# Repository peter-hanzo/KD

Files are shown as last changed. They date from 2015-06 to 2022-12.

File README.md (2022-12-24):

## Круглый дом (КД) 
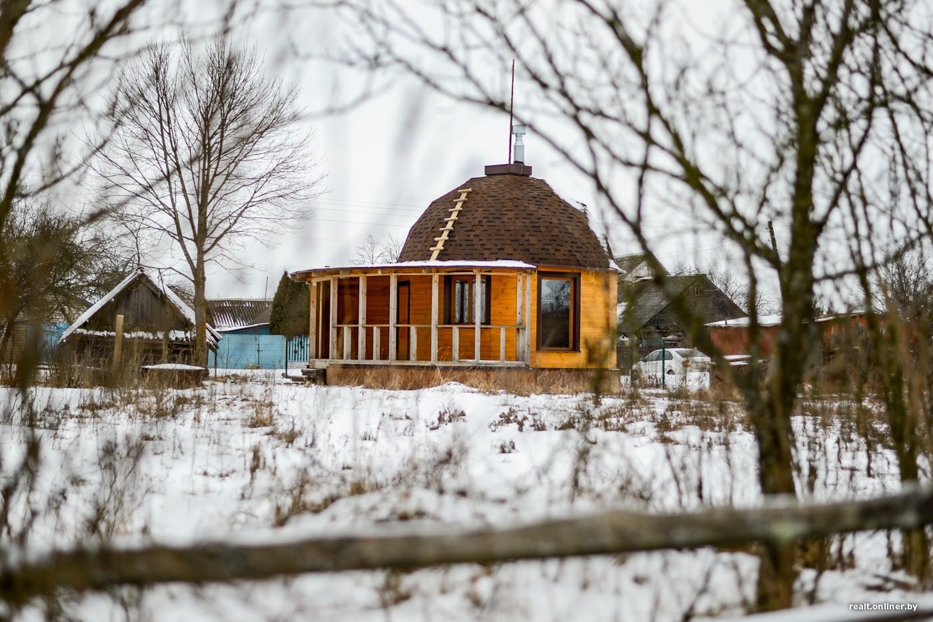
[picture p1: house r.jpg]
Текущий внешний вид


### Общие данные:
Одноквартирного жилого дом летнего типа _общей площадью 65м2_  
Выполнен в соответствии с функциональными желаниями Заказчика.  
Предназначен для строительства в Минской области.  

### Строительные решения разработаны для следующих условий:

Температура воздуха наиболее холодной пятидневки -30°С  
_Снеговая нагрузка:_ 180кг/м2  
_Скоростной напор ветра:_ 21 м/с на м2 
Расчетная температура наружного воздуха -35°С/+35°С  
Продолжительность периода со среднесуточной температурой менее 0°С =231сут  
Средняя максимальная температура воздуха наиболее теплого месяца +25°С  
Количество осадков за год 582мм  
Преобладающее направление ветра сентябрь-март «СЗ». март-сентябрь «ЮЗ»  
Зона влажности - нормальная  

### Планировочное решения:

За условную отметку 0.000 принят уровень чернового пола первого этажа.  
Планировка решена в 2-х уровнях:  
На первом этаже: прихожая, кладовая, коридор, гостиная, кухня, сан.узел, открытая терраса общей площадью 15 м2  
На втором этаже: спальня  
Первый и второй этажи соединены лестницей из деревянных конструкций  
Расположение дома на земельном участке обеспечивает естественную инсоляцию жилых помещений в соответствии требованиями энергоэффективности    
### Конструктивное решения:
Несущими конструкциями здания являются наружные стены.  
Пространственная жесткость здания обеспечивается совместной работой наружных и внутренних стен с элементами перекрытии.  
Ограждающие конструкции здания выполнены из дерева с утеплением из льна.  
Тип фундамента - свайно-буронабивной.  
На основании расчетных нагрузок от здания и типа грунта глубина заложения свай составляет 1,8м, диаметр свай 300мм.  
Наружные стены — доска 150*50 естественной влажности, льняной утеплитель 100мм + 50мм 
Стены обшиты имитацией бруса с вентилируемым фасадом.  
В качестве опоры второго этажа использован брус 200х200мм.  
Отделка помещения: Половая доска, фанера ФСФ, деревянный брус.  
* Перекрытия:_ деревянная балка.
* Лестница:_ деревянная  
* Крыша: Купольная из деревянных конструкций геодезического типа.  
* Кровля : битумная черепица  
* Окна: Деревянные с двойным стеклопакетом  
* Двери: деревянные  
* Полы: деревянные  

### Инженерное оборудование:
В жилом доме предусматривается следующее инженерное оборудование:  
* Отопление - от электрический кварцевых обогревателей  
* Холодное водоснабжение - от скважины глубиной 8м  
* Канализация — местная, бетонные кольца с переливом  
* Электроснабжение централизованное от местной электросети 220В  
* Газоснабжение  - отсутствует  

### Основные показатели проекта:
Этажность: 2 этажа  
Площадь застройки: 90 м2  
Общая площадь: 65 м2  
Жилая площадь: 35 м2  
Строительный объем: 170 м3  	
Класс ответственности здания: 4й — временные общественные здания и малоэтажные жилые дома с минимальным благоустройством  
Степень долговечности: 3я —  с пониженным сроком службы (не менее 20 лет)   
Степень огнестойкости: 5я - сгораемые  

Читайте все посты по данному проекту [в блоге](https://rdnk.by)

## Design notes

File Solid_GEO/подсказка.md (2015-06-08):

frame.SLDASM - сама модель.
frame.SLDDRW - некое подобие документации (в корне папки аналогичная pdf'ка).

Если нет solidworks'a можно посмотреть в бесплатном просмотрщике edrawing viewer 2015
http://www.edrawingsviewer.com/ed/download.htm.

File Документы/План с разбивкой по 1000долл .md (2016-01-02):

КРОВЛЯ ДОМА 
- [ ] Смонтировать дверь в доме 100 (80-120)
- [ ] Сделать обрамления окон в доме 60 (40-80)		
- [ ] Закрепить верхний слой кровли дома 450 (300-600)
- [ ] Смонтировать водостоки дома 375 (250-500)
- [ ] *** 985$

ПОЛНАЯ ЗАЩИТА ДОМА ОТ ВНЕШНЕЙ СРЕДЫ
- [ ] Смонтировать окна	в доме 1100 (750-1450)
- [ ] *** 1100$

КРЫЛЬЦО + ЭЛЕКТОПРОВОДКА ПО ВСЕМУ ДОМУ
- [ ] Смонтировать каркас крыльца 40 (30-50)  
- [ ] Подшить пол крыльца 20 (10-30)
- [ ] Уложить чистовой пол крыльца 55 (30-80) 
- [ ] Смонтировать крышу крыльца 75 (50-100)
- [ ] Смонтировать лестницу крыльца 35 (20-50)		
- [ ] Нанести пропитку на внешнюю обшивку стен дома 75 (50-100)
- [ ] Проложить кабель от счетчика к дому 150 (100-200)				
- [ ] Установить электроящик и автоматы 165 (80-250)		
- [ ] Проложить кабель в доме +розетки 200 (100-300)
- [ ] *** 930$

УТЕПЛЕННЫЙ ПОЛ ПЕРВОГО ЭТАЖА
- [ ] Смонтировать утеплитель 6м3 пола первого этажа 225 (150-300)
- [ ] Смонтировать мембрану пола первого этажа 100 (80-120)		
- [ ] Смонтировать подшивку пола первого этажа 225 (150-300)
- [ ] Зашить подпольное простанство дома 265 (180-350)				
- [ ] *** 815$

УТЕПЛЕННЫЙ И ОБШИТЫЙ КУПОЛ ДОМА
- [ ] Смонтировать утеплитель в куполе 700 (400-1000) 			
- [ ] Смонтировать внутренюю мембрану в куполе 140 (80-200)
- [ ] Смонтировать внутренюю обшивку в куполе 550 (300-800)
- [ ] *** 1390$

УТЕПЛЕННЫЕ И ОБШИТЫЕ СТЕНЫ ДОМА
- [ ] Смонтировать утеплитель в стены дома 550 (300-800)			
- [ ] Смонтировать внутренюю мембрану в стены дома 100 (50-150)
- [ ] Смонтировать внутренюю обшивку стен дома 450 (300-600)
- [ ] *** 1100$

ОТОПЛЕНИЕ В ДОМЕ
- [ ] Установить систему отопления в доме 900 (200-1600)			
- [ ] *** 900$

ВОДОПРОВОД И КАНАЛИЗАЦИЯ		
- [ ] Установить канализацию 800 (400-1200)
- [ ] Прокложить трубы канализации и водопровода 200 (100-300)
- [ ] Установить насос для водопровода 325 (200-450)
- [ ] *** 1325$

ВТОРОЙ ЭТАЖ
- [ ] Смонтировать каркас второго этажа 125 (50-200)
- [ ] Уложить утеплитель второго этажа 200 (100-300) 
- [ ] Подшить потолок второго этажа 100 (50-150) 
- [ ] Уложить чистовой пол  второго этажа 200 (100-300)
- [ ] Смонтировать ограждение второго этажа 200 (50-350)
- [ ] *** 825$

ЛЕСТНИЦА + ПОЛ ПЕРВОГО ЭТАЖА
- [ ] Изготовить лестницу второго этажа 275 (50-500)	
- [ ] Смонтировать лестницу второго этажа 100 (50-150)
- [ ] Смонтировать чистовой пол первого этажа 400 (300-500)			
- [ ] *** 775$

НЕОТАПЛИВАЕМЫЙ САНУЗЕЛ С КРЫШЕЙ
- [ ] Смонтировать фундамент санузла 125 (50-200)
- [ ] Смонтировать обвязку санузла 200 (100-300)
- [ ] Собрать каркас стен санузла 150 (100-200)
- [ ] Собрать купол санузла 225 (150-300)
- [ ] Накрыть крышу санузла 300 (200-400)
- [ ] Установить окно санузла 250 (200-300)
- [ ] Установить дверь санузла 115 (80-150)
- [ ] *** 1365$	

ПОЛНОЦЕННЫЙ ОТАПЛИВАЕМЫЙ САНУЗЕЛ						
- [ ] Подшить пол санузла 100 (50-150)		
- [ ] Утеплить пол санузла 100 (50-150)
- [ ] Смонтировать чистовой пол санузла 225 (150-300)
- [ ] Смонтировать черновой пол санузла 150 (100-200)
- [ ] Смонтировать внешнюю мембрану	санузла 60 (40-80)	
- [ ] Утеплить купол санузла 225 (150-300)
- [ ] Утеплить стены санузла 175 (100-250)							
- [ ] Зашить подпольное простанство санузла 100 (50-150)
- [ ] Установить систему отопления в санузле 150 (100-200)	
- [ ] Установить бойлер 300 (150-450)  
- [ ] *** 1585$

ВЕРАНДА С КРЫШЕЙ	
- [ ] Смонтировать фундамент веранды 125 (50-200)
- [ ] Смонтировать обвязку веранды 200 (100-300)
- [ ] Уложить пол веранды 225 (150-300) 
- [ ] Пропитать пол веранды 75 (50-100)
- [ ] Смонтировать крышу веранды 450 (300-600)
- [ ] Смонтировать лестницу веранды 100 (50-150)
- [ ] *** 1175$

ЗОБОР И РАЗМЕТКА УЧАСТКА		
- [ ] Установить забор 50м 600 (300-900)
- [ ] Установить ворота и калитку 175 (50-300)
- [ ] Уложить дорожки 200 (100-300)
- [ ] *** 975$

ПОРЯДОК НА УЧАСТКЕ
- [ ] Переместить гараж 100 (50-150)
- [ ] Распилить, поколоть, сложить дрова 175 (100-250)		
- [ ] Выровнять уровень грунта на участке 300 (200-400)
- [ ] Сделать отмостку вокруг дома 200 (100-300)
- [ ] Завести плодородный грунт 225 (150-300)
- [ ] *** 1000$

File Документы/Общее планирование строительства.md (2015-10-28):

- [x] Выбрать участок  
- [x] Обеспечить коммуникаций  
	- [x] Дороги (получить гарантированный подвоз материалов)  
	- [x] Электричество  (постоянно иметь 220V на участке)
	- [x] Вода  (постояно иметь воду в любом количестве)
- [x] Подготовить участок  
	- [x] Получить разрешения на снос старых построек  
	- [x] Разобрать старые постройки  
	- [x] Расчистить площадку под застройку  
	- [x] Обозначить границы участка согласно документам  
	- [x] Выбрать расположение будущего дома и его размеры  
- [x] Разработать архитектуру  
	- [x] Выбрать архитектора  
	- [x] Составить планировку внутренних помещений  
	- [x] Определить расположение дверей и окон  
- [x] Разработать конструкцию всего дома  
	- [x] Фундамент  
		- [x] Выбрать тип фундамента 
		- [x] Определить точное расположение на участке 
		- [x] Рассчитать глубину, ширину, высоту  
	- [x] Стены  
		- [x] Создать конструкцию  
		- [x] Выбрать материалы конструкции  
		- [ ] Выбрать утеплитель 
		- [ ] Выбрать тип отделки  
	- [x] Крыша  
		- [x] Создать форму и конструкцию  
		- [x] Выбрать материалы  
		- [ ] Выбрать утеплитель для пола
		- [ ] Выбрать утеплитель для купола
		- [ ] Выбрать утеплитель для стен
	- [ ] Окна и двери  
		- [x] Выбрать конструкцию  
		- [x] Определить точные размеры
		- [x] Определить расположение
		- [ ] Выбрать материал изготовления  
	- [ ] Электрика
		- [ ] Определить путь прокладки кабеля от щитка	
		- [ ] Определить точное расположение розеток и выключателей  
		- [x] Рассчитать максимальные нагрузки  
		- [ ] Определить место установки счетчика  
		- [ ] Рассчитать необходимые материалы  
	- [ ] Канализация  
		- [ ] Определить точное расположение  
		- [ ] Выбрать тип конструкции  
		- [ ] Расчитать необходимый объем  
		- [ ] Выбрать материалы  
- [x] Получить разрешение на стройку  
	- [x] Выяснить необходимый список документов и орган согласования  
	- [x] Подать пакет документов  
- [x] Построить здание  
	- [x] Фундамент  
		- [x] Рассчитать и закупить материалы  
		- [x] Связать арматуру
  		- [x] Заготовить трубки из руберойда
		- [x] Разметить границы и уровни  
		- [x] Залить и обрезать в уровень
	- [x] Обвязка и пол  
		- [x] Рассчитать  и закупить брус, лаги, крепления  
		- [x] Нарезать брус в размер под углом  
		- [x] Нанести пропитку  
		- [x] Смонтировать обвязку
		- [ ] Смонтировать мембрану пола первого этажа (80-120)		
		- [ ] Смонтировать подшивку пола первого этажа(150-300)
		- [ ] Смонтировать утеплитель 6м3 пола первого этажа(150-300)		
		- [ ] Смонтировать чистовой пол первого этажа(300-500)
	- [ ] Стены  
		- [x] Расчитать и закупить доску  
		- [x] Нарезать заготовки
		- [x] Заготовить сегменты стен
		- [x] Смонтировать сегменты стен			
		- [x] Смонтировать внешнюю мембрану			
		- [x] Ненести пропитку на внешнюю обшивку стен дома (50-100)
		- [x] Смонтировать внешнюю обшивку дома (0)
		- [ ] Зашить подпольное простанство дома(180-350)		
		- [ ] Смонтировать утеплитель в стены дома (300-800)			
		- [ ] Смонтировать внутренюю мембрану в стены дома(50-150)			
  		- [ ] Смонтировать внутренюю обшивку стен дома (300-600)
	- [ ] Купол  
		- [x] Расчитать и закупить доску  
		- [x] Нарезать заготовки
		- [x] Заготовить сегменты стен
		- [x] Смонтировать сегменты стен			
		- [ ] Смонтировать утеплитель в купол(400-1000) 			
		- [ ] Смонтировать внутренюю мембрану в купол (80-200)			
  		- [ ] Смонтировать внутренюю обшивку в купол (300-800)		
	- [ ] Крыша  
		- [x] Закупить крепления, доску, фанеру, бруски, кровлю, водостоки 
		- [x] Нарезать доску в размер под углом  
		- [x] Смонтировать каркас купола  
		- [x] Зашить каркас купола пленкой  
		- [x] Смонтировать бруски
  		- [x] Заготовить треугольники из фанеры
		- [x] Смонтировать треугольники  
		- [x] Приклеить нижний слой кровли  
		- [ ] Закрепить верхний слой кровли дома (300-600)  
		- [ ] Смонтировать водостоки дома(250-500)
	- [ ] Окна и двери  
		- [ ] Смонтировать проемы для окон в доме (0)
		- [ ] Смонтировать проемы для двери в доме (0)
		- [ ] Смонтировать дверь в доме (80-120)
		- [ ] Смонтировать окна	в доме (750-1450)
		- [ ] Сделать обрамления окон в доме (40-80)		
	- [ ] Второй этаж  
		- [ ] Смонтировать каркас второго этажа (50-200)
		- [ ] Уложить утеплитель второго этажа (100-300) 
		- [ ] Подшить потолок второго этажа (50-150) 
		- [ ] Уложить чистовой пол  второго этажа (100-300)
		- [ ] Смонтировать ограждение второго этажа (50-350)
		- [ ] Изготовить лестницу второго этажа (50-500)	
		- [ ] Смонтировать лестницу второго этажа(50-150)
	- [ ] Крыльцо  
		- [x] Смонтировать обвязку
		- [ ] Смонтировать каркас крыльца (30-50)  
		- [ ] Подшить пол крыльца (10-30) 
		- [ ] Уложить чистовой пол крыльца (30-80) 
		- [ ] Смонтировать крышу крыльца (50-100)
		- [ ] Смонтировать лестницу крыльца (20-50)
	- [ ] Веранда  
		- [ ] Смонтировать фундамент веранды (50-200)
		- [ ] Смонтировать обвязку веранды (100-300) 
		- [ ] Уложить пол веранды (150-300) 
		- [ ] Пропитать пол веранды (50-100) 		
		- [ ] Смонтировать крышу веранды (300-600)
		- [ ] Смонтировать лестницу веранды (50-150)
	- [ ] Обуствойство быта  
		- [ ] Смонтировать раковину в доме (50-100)
		- [ ] Смонтировать шкафы в доме(100-300) 
	- [ ] Отдельный санузел  
		- [ ] Смонтировать фундамент санузла (50-200)
		- [ ] Смонтировать обвязку санузла (100-300)
		- [ ] Собрать каркас стен санузла (100-200)
		- [ ] Собрать купол санузла (150-300)
		- [ ] Накрыть крышу санузла (200-400)
		- [ ] Подшить пол санузла (50-150)		
		- [ ] Утеплить пол санузла (50-150)
		- [ ] Смонтировать чистовой пол санузла (150-300)
		- [ ] Смонтировать внешнюю мембрану	санузла (40-80)	
		- [ ] Утеплить стены санузла санузла (100-250)
		- [ ] Утеплить купол санузла санузла (150-300)
		- [ ] Установить окно санузла (200-300)
		- [ ] Установить дверь санузла (80-150)
		- [ ] Зашить подпольное простанство санузла (50-150)
- [ ] Канализация и водопровод
	- [ ] Прокладка труб (100-300)
	- [ ] Установка септика (300-3200)
	- [ ] Установка насоса (200-450)
	- [ ] Установка бойлера (150-450)  	
- [ ] Электричество
	- [ ] Прокладка кабеля от счетчик к дому (100-200)
   	- [ ] Установка электро ящика и автоматов (80-250)		
   	- [ ] Прокладка кабеля в доме +розетки (100-300)
- [ ] Благоустройство територии
	- [ ] Выровнять уровень грунта на участке (200-400)
   	- [ ] Завести плодородный грунт (150-300)
   	- [ ] Распилить, поколоть, сложить дрова (100-250)		
   	- [ ] Установить забор 50м (300-900)
   	- [ ] Переместить гараж (50-150)		
   	- [ ] Установить ворота и калитку (50-300)
   	- [ ] Сделать отмостку вокруг дома (100-300)
   	- [ ] Уложить дорожки (100-300)
- [ ] Установить систему отопления в доме (200-1000)
- [ ] Установить систему отопления в санузле (100-200)

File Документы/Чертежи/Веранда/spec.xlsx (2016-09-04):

Поз | Сечение, мм | Длина, мм | Кол-во
1 | 150x50 | 3015 | 26
2 |  | 2150 | 27
3 |  | 1245 | 4
4 |  | 2364 | 4
5 |  | 2283 | 4
6 |  | 2160 | 2
7 |  | 567 | 1
8 |  | 528 | 1
9 |  | 533 | 2
10 |  | 600 | 2
11 |  | 1099 | 1
12 |  | 1350 | 1
13 |  | 1099 | 2
14 |  | 504 | 1
15 |  | 480 | 2
16 |  | 516 | 1
17 |  | 646 | 2
18 |  | 1312 | 2
19 |  | 1306 | 2
20 |  | 1188 | 1
21 |  | 2058 | 1
22 |  | 900 | 4
23 |  | 1046 | 1
24 |  | 1317 | 2
25 |  | 1317 | 2
26 |  | 1035 | 1
27 |  | 1081 | 1
28 |  | 1345 | 2
29 |  | 1345 | 2
30 |  | 1081 | 1
31 |  | 1144 | 1
32 |  | 1316 | 1
33 |  | 1316 | 1
34 |  | 2198 | 2
35 |  | 2203 | 2
36 |  | 2306 | 2
37 |  | 1256 | 4
40 |  | 2600 | 44
41 |  | 2310 | 2
42 |  | 2305 | 2
43 |  | 968 | 9
44 |  | 2467 | 1
45 |  | 2462 | 1
46 |  | 2376 | 1
47 |  | 2371 | 1
48 |  | 808 | 3
49 |  | 1050 | 2
50 |  | 1387 | 2
51 |  | 1037 | 2
52 |  | 687 | 2
53 |  | 1268 | 2
54 |  | 975 | 2
55 |  | 683 | 2
56 |  | 1296 | 2
57 |  | 990 | 2
58 |  | 685 | 2
59 |  | 1245 | 2
60 |  | 962 | 2
61 |  | 682 | 2
62 |  | 1292 | 2
63 |  | 988 | 2
64 |  | 685 | 2
65 |  | 1211 | 2
66 |  | 918 | 2
67 |  | 625 | 2
68 |  | 2336 | 2
69 |  | 2312 | 2
70 |  | 2293 | 2
71 |  | 2313 | 2
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

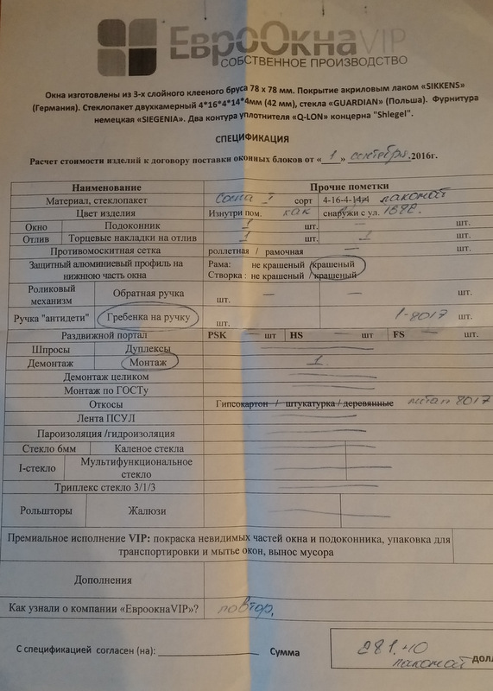
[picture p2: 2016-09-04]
Документы/Фактические расходы/2016-09/2016-09-01 - 573.00 - 291$ - Санузел - изготовление и монтаж окна.jpg

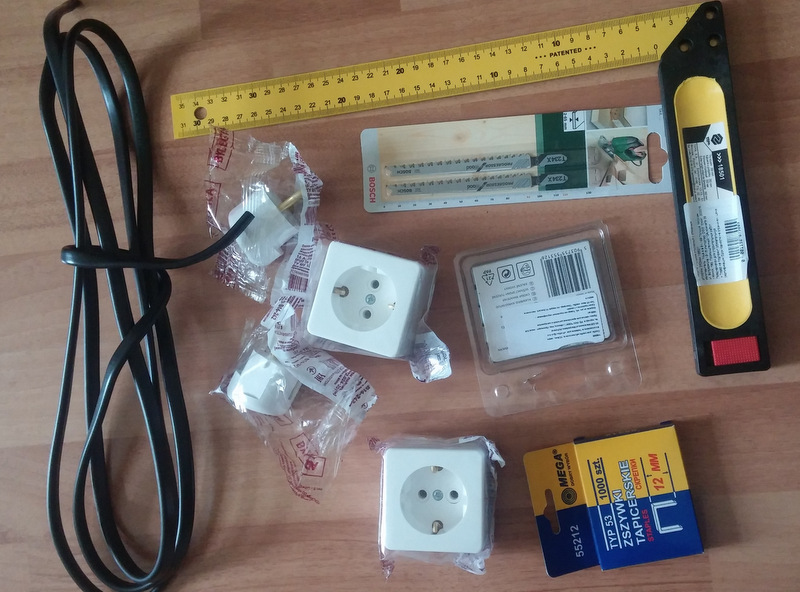
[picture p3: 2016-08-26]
Документы/Фактические расходы/2016-08/2016-08-15 - 55.00 - 28$ - Первый этаж - инструмент и комплектующие.jpg

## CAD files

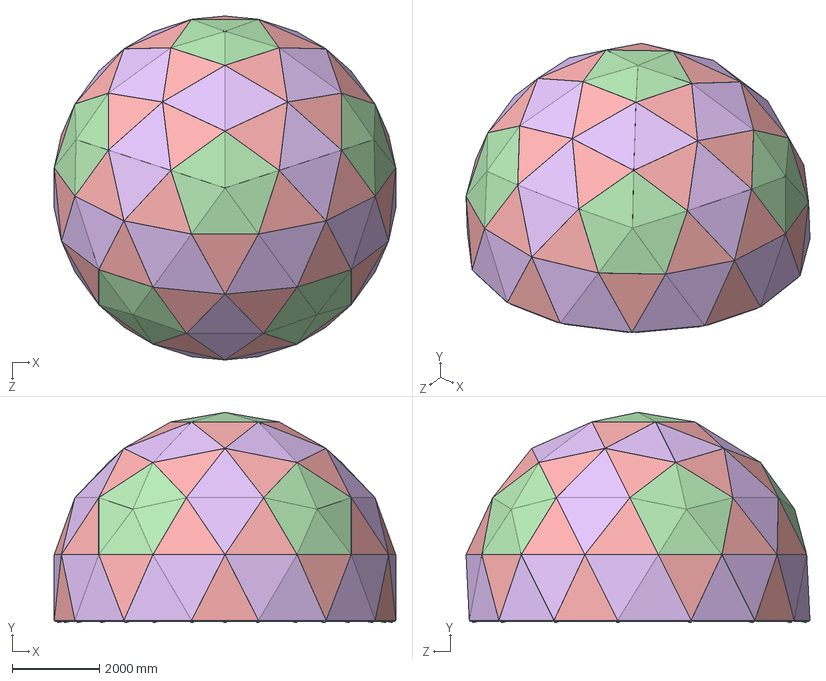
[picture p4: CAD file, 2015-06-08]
Solid_GEO/frame/frame.SLDASM
7818.9 x 4812.3 x 7874.0 mm
board_1 x 45
plate_1 x 180
pin x 760
nut x 1520
board_2 x 35
plate_2 x 140
board_3 x 80
plate_3 x 320
board_4 x 30
plate_4 x 120
pipe x 90
triangle_1 x 30
triangle_2 x 35
triangle_3 x 40

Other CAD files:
Документы/Чертежи/Архитектура (эскизный)/генплан v2.dwg
Документы/Чертежи/Конструктив/треугольники.dwg
Документы/Чертежи/Крыша/Металл-профиль.dwg
Что бывает/Чертежи/купол.dwg
Документы/Чертежи/Конструктив/Схема сборки и обшивки каркаса.dwg
Что бывает/Чертежи/Polusfera_v_liniakh_3V_6m.dwg
Документы/Чертежи/Конструктив/Спецификация балок обвязки.dwg
Документы/Чертежи/Конструктив/терасса.dwg
Документы/Чертежи/Конструктив/пластины и уголок.dwg
Solid_GEO/frame/board_1.SLDPRT
Solid_GEO/frame/board_2.SLDPRT
Solid_GEO/frame/frame.SLDDRW
Solid_GEO/frame/frame.SLDPRT
Solid_GEO/frame/nut.SLDPRT
Solid_GEO/frame/pin_nut.SLDASM
Solid_GEO/frame/pipe.SLDPRT
Solid_GEO/frame/plate_1.SLDPRT
Solid_GEO/frame/plate_2.SLDPRT
Solid_GEO/frame/plate_4.SLDPRT
Solid_GEO/frame/triangle_1.SLDPRT
Solid_GEO/frame/triangle_2.SLDPRT
Solid_GEO/frame/triangle_3.SLDPRT
Документы/Чертежи/Архитектура (эскизный)/генплан.dwg
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

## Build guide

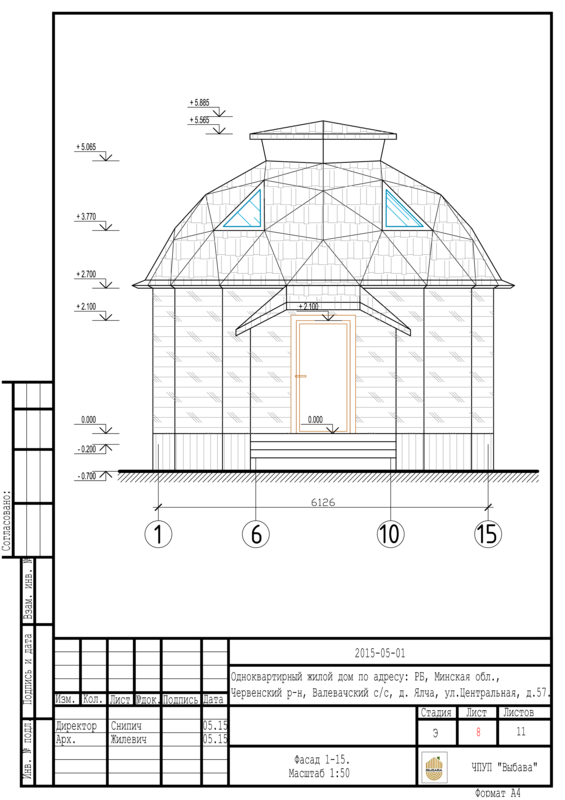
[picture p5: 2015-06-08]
Документы/Чертежи/Архитектура (эскизный)/printable/лист 8 фасад.png

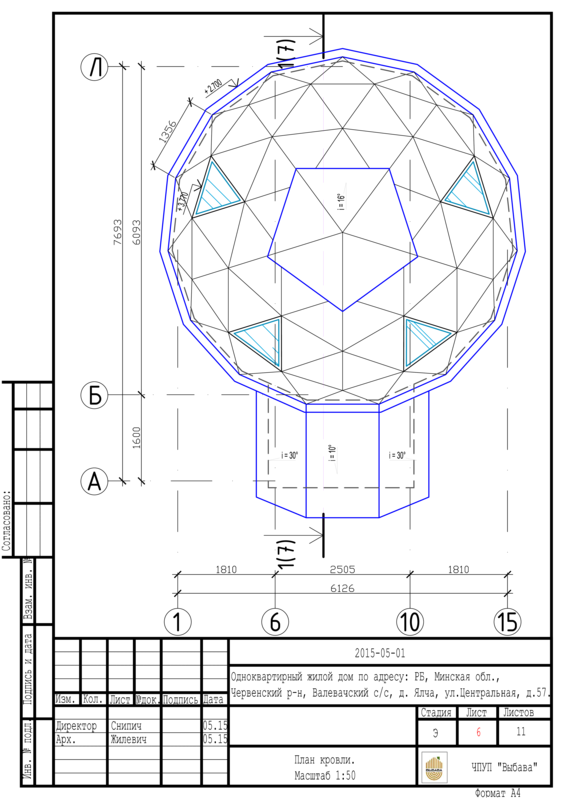
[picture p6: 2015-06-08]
Документы/Чертежи/Архитектура (эскизный)/printable/лист 6 план кровли А4.png

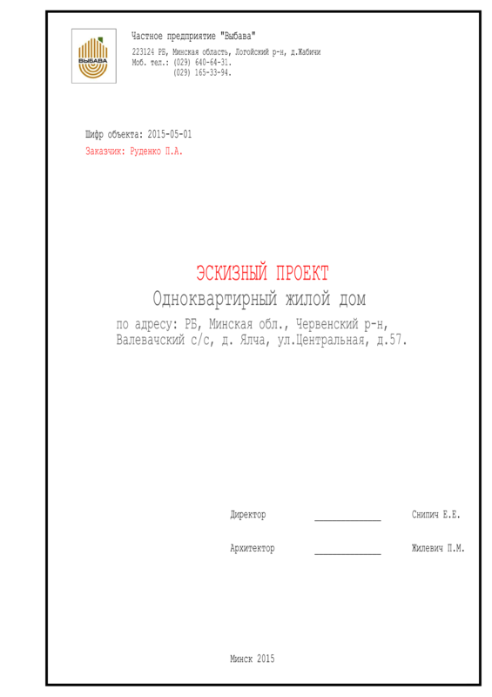
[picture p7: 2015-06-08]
Документы/Чертежи/Архитектура (эскизный)/printable/титульник А4.png

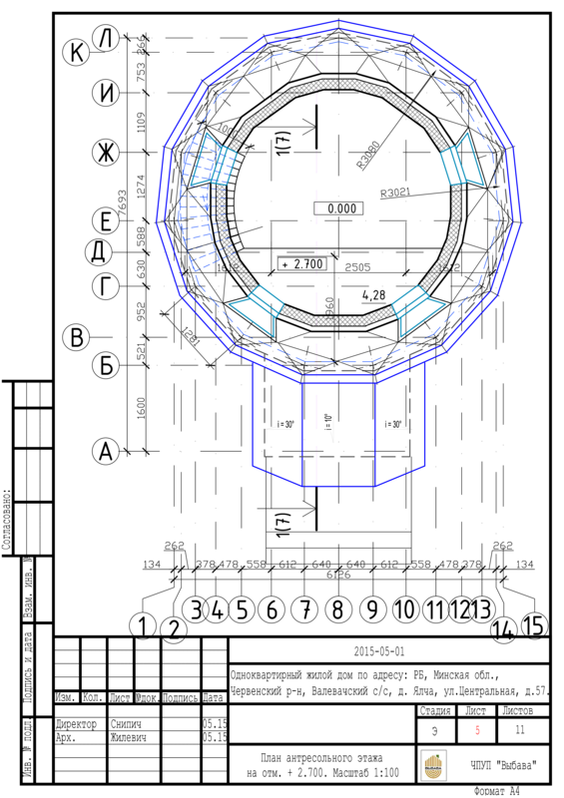
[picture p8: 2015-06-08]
Документы/Чертежи/Архитектура (эскизный)/printable/лист 5 план антресолей А4.png

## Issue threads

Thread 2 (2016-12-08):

переписать описание в корне проекта

Komzpa, 2016-12-08:
Слова "самостоятельно" и "$1000 ежемесячно" - это не про этот проект :)

RudenkoPeter, 2016-12-08:
согласен, уже не про этот)

RudenkoPeter, 2016-12-19:
Так норм? "Каждый год комфортно проживать в период весна-осень"

Komzpa, 2016-12-19:
у этого дома уже зафиксирована площадь, этажность и другие параметры. можно писать их, а не требования двухгодичной давности :)

RudenkoPeter, 2016-12-19:
Может убрать "требования" и написать паспорт объекта?

Komzpa, 2016-12-19:
похоже на то.

Closed 2017-05-21.

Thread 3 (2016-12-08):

Схема коммуникаций

Komzpa, 2016-12-08:
Нужна схема:
 - всей электрики в доме (установленной и планируемой);
 - всей канализации в доме (установленной и планируемой).

RudenkoPeter, 2016-12-08:
Достаточно ли сделать в 3д  или нужны чертежи?

RudenkoPeter, 2016-12-08:
Вот в таком виде + отдельная модель в Sketchup ?
https://sketchfab.com/models/3d5a06f5ac784347bc1c8a6937288433

Komzpa, 2016-12-08:
Нужна схема, по которой будет удобно проводить археологические расковыивания стен, и на которой будет удобно чёркать "тут мало розеток".

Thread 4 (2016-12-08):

Инструкция по техобслуживанию

Komzpa, 2016-12-08:
Что выключать на зиму?
Что отключать, что подключать?
Как слить воду из водопровода?

RudenkoPeter, 2016-12-08:
сделаю видео-инструкцию

RudenkoPeter, 2017-01-30:
инструкцию буду делать после: утепления водопровода, монтажа серверной, обустройства санузла т.к. вся схема водопровода и электрики изменится

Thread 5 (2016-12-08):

Серверная

Komzpa, 2016-12-08:
В доме нет серверной.

Серверная должна:
 - быть сухой;
 - кондиционироваться (держать +5..+30 вне зависимости);
 - соединяться по Ethernet c остальным домом;
 - быть шумосветоизолированной от спального места;
 - иметь ИБП;
 - иметь интернет.

RudenkoPeter, 2016-12-08:
Надо определить точное и постоянное место под серверную. Варианты: там где сейчас или рядом с электрощитком.

Komzpa, 2016-12-08:
Как это может выглядеть, если рядом с электрощитком? :)

Была ещё мысль о тёплой коробке под домом.

RudenkoPeter, 2016-12-08:
Если делать что-то под домом, то и электрощиток туда же. Два шкафа независимых. Надо подумать про легкий доступ. А еще сервера закапывают под землю))

RudenkoPeter, 2016-12-19:
какие должны быть параметры у ИПБ?

Komzpa, 2016-12-19:
ИПБ должен быть из списка совместимости с NUT, http://networkupstools.org/stable-hcl.html
Продаваться в розницу в Беларуси, мощность - наибольшая из доступных.

RudenkoPeter, 2017-01-03:
Хватит ли того ИПБ который сейчас есть?
Серверную решили сделать под полом рядом с крыльцом. Предлагаю сделать утепленный каркас и установить в него вот этот [ящик](http://regul.by/images/shitmonpan44.jpg). С одной стороны сделать электрику, со второго серверную

Komzpa, 2017-01-04:
как закрывается ящик?
куда направлена дверь?
как реагирует на разлитую на него воду при такой установке - затеканием внутрь или сбрасыванием наружу?
можно ли будет его выломать смещением вбок?

Komzpa, 2017-01-04:
бесперебойника должно хватить.
кроме того, хочется разводки, электрики, которая бы позволила легко выключить весь дом, но не серверную.

RudenkoPeter, 2017-03-17:
**Планируется следующее:**
2.1	установка серверного шкафа
2.2	заливка основания под серверный шкаф
2.3	подключить дополнительные автоматы
2.4	подключить умное освещение
2.5	переустановить электроящик

Пункты (2.1) (2.2) взаимосвязаны и идут перед (2.3) (2.4) (2.5)
Пункты (2.3) (2.4) (2.5) делает один специалист, поэтому желательно их не разделять.

Closed 2018-04-17.

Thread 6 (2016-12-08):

Шторы

Komzpa, 2016-12-08:
Окна очень тонкие и прозрачные.
Нужен механизм их закрывания и утепления.

RudenkoPeter, 2016-12-08:
Механизм должен быть ручной или автоматическое управление через умный дом?

Komzpa, 2016-12-08:
Желательно всё автоматизировать :)

видится что-то вроде http://rollet.by/product/rollety/rollety-zashchitnye-alutech

RudenkoPeter, 2016-12-08:
Если нет страхов вандализма, возможно оптимальнее пойти по этому пути:
https://goo.gl/photos/5ViWvnwzXYPmfN2V9
https://goo.gl/photos/Q2y5RmHvekgfdZQE6

Komzpa, 2016-12-08:
Утепление? Там сейчас одно стекло и всё.

RudenkoPeter, 2016-12-19:
Сейчас рассматриваю возможность монтажа ролет по нескольким вариантам: http://sunset.kiev.ua/images/stories/zashhitnye-rolety/rolstavni-11.jpg

RudenkoPeter, 2017-01-03:
Рольставни на окно под крышей веранды поставить не сможем, но это не страшно т.к. летом в него прямое солнце не попадает, а зимой в будущем возможно веранда будет закрытая. На окно с улицы и большое ставим автоматические рольставни такого же цвета как и обрамление окон. Спрятать короб в стену не получится, поэтому будет так же как на фото. На большое окно предлагаю поставить усиленные противовандальные, а на окно с улицы (северное) утепленные с шумоподавлением. http://ankorokna.ru/wp-content/uploads/2016/04/283271983-1024x768.jpg

RudenkoPeter, 2017-03-17:
**Планируется сделать:**
7.1	установить рольставни

Пункт (7.1) довольно затратный и взаимосвязан с пунктам (9.2) который перенесен на 2018 год
Утеплять окна есть смысл только после полного утепления стен и купола. Тк освещение из окон зимой не требуется, то можно сделать временное утепление из остатков утеплителя.

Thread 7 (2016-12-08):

Акустика

Komzpa, 2016-12-08:
У дома есть проблемы с акустикой:
 - очень громко слышно всё, что происходит на улице;
 - со спального места слышно, что происходит в туалете (вероятно, можно починить, сделав шумную вытяжку вместе со светом в туалете?);
 - музыка из колонок очень хитро отражается от дома, в результате звучание очень неравномерное - шаг влево-вправо, и звук гаснет или становится в два раза громче;
 - щиток жужжит - надо вынести за пределы жилой зоны;
 - переключатели розеток громко щёлкают - надо вынести за пределы жилой зоны.

RudenkoPeter, 2016-12-08:
Есть вариант убрать переключатели в щиток, а сам щиток не переносить, а звукоизолировать.

Komzpa, 2016-12-08:
Сейчас щиток висит на паре шурупов, а торчащий из него пук проводов не видно, как будет укладываться в стену. Надёжных способов звукоизолировать я не вижу :)

RudenkoPeter, 2016-12-08:
Под "переносить" я услышал - вынести на веранду или в санузел. Это проблемно + доп расходы

Komzpa, 2016-12-08:
в общем, это всё надо комплексно порешать, и желательно моделированием, а не "давайте соберём и узнаем, что не получилось" :)

RudenkoPeter, 2016-12-19:
Пирог стены сейчас: 12мм обшивка + 0,5мм мембрана. Неудивительно что звуки с улицы легко попадают в помещение. Планируется следующий пирог: 12мм обшивка+0,5 мембрана+150мм утеплитель из льна +12мм обшивка купола и 34мм обшивка стен. Итого: вместо 12,5мм толщина стены будет 174-196мм, что значительно уменьшит попадание внешних звуков в помещение.

Komzpa, 2016-12-19:
Как планируется решать проблему эха и переотражений?

RudenkoPeter, 2016-12-19:
думаю над тем, как это можно промоделировать

RudenkoPeter, 2017-01-05:
Из акустических материалов есть два варианта:
[Перфорированные гипсокартонные листы](http://acoustic.by/components/com_jshopping/files/img_products/saundline-aoustic-star.jpg) с различным рисунком
[Акустические панели](http://acoustic.by/components/com_jshopping/files/img_products/heradesign-superfine4.jpg) с различной текстурой и цветом

[Примеры использования перфорации](http://strport.ru/stroitelstvo-domov/perforirovannye-paneli-osobennosti-dostoinstva-primenenie) в помещениях.

Komzpa, 2017-01-05:
что насчёт ковров? :)

RudenkoPeter, 2017-01-05:
[Ковры на стенах](http://1.bp.blogspot.com/-PbUYghLysYQ/VcnTVbCj1SI/AAAAAAAAnfY/C_8DfXCUc_E/s1600/12_2.jpg) конечно можно, но на купол ковер не приделать, только [акустические ткани](http://www.acoustic-group.by/data/goodscatalog/goods/79/list-thmb.jpg)

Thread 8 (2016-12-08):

Закрытие периметра

Komzpa, 2016-12-08:
Опыт установки камеры показал себя хорошо, надо закрыть подобным образом весь периметр.

Надо:
 - посчитать места установки камер, чтобы они снимали полный круговой обзор с нахлёстом;
 - оценить другие места (веранда? смотреть на окна/серверную снаружи?);
 - определить модель и способ подключения (как минимум - нужны провода до серверной, USB не получится отнести больше, чем на 5 метров);

RudenkoPeter, 2016-12-08:
нужны ли камеры в доме или только внешний конур наблюдаем?

RudenkoPeter, 2016-12-08:
в каком месте планируется постоянное место для серверной? Там где она сейчас?

Komzpa, 2016-12-08:
место под серверную мы определим в #5 :)

RudenkoPeter, 2017-01-30:
на данный момент не решен только третий пункт?

Komzpa, 2017-01-30:
сейчас камеры стоят как придётся. как минимум, кабели для них нужно посчитать.

RudenkoPeter, 2017-01-30:
Тогда объединяю эту задачу вместе с "схема всей электрики в доме"

Komzpa, 2017-01-30:
С чего вдруг? тут как минимум не просто провода будут, а какие-то контроллеры (оставлять всё в режиме "всем рулит ноутбук" - не хочется) :)

RudenkoPeter, 2017-01-30:
Тогда отдельно сделаю "схему видеонаблюдения": провода, точки, контроллеры, углы обзора

RudenkoPeter, 2017-02-22:
Не ясно как подключать USB камеры, которые будут от серверной дальше 5метром. Вместо них будут IP камеры подключенные по Wi-fi или пачкордом?

Komzpa, 2017-02-23:
Куда, как и по какому принципу они умеют писать видео?

RudenkoPeter, 2017-02-23:
продавцы не смогли ответить.
Есть дополнительная инфа на сайте: http://optimus-cctv.ru/online-video
Каталог продукции: http://optimus-cctv.ru/files/katalog_optimus.pdf
Так же нашел руководство по подключению:
http://www.sakurabel.com/sitefiles/1/13/777/3790/3791/3802/4009/4010/_______________________________________________________________ip_____________e_1.pdf

Komzpa, 2017-02-23:
IE activeX из последней pdf сразу идут лесом :)

ищем нормальный mpeg/x264 поток, втыкаемый в linux/motion.

RudenkoPeter, 2017-02-23:
тут народ обсуждает подобную тему:
https://www.linux.org.ru/forum/desktop/11558534
http://majordomo.smartliving.ru/Main/ScNetCam

Но понять конкретные требования к камере, чтобы найти ее в магазине я не смог.

RudenkoPeter, 2017-03-23:
Еще один вариант камеры: http://videocamera.by/katalog/sistemy-videonablyudeniya/byudzhetnye-ip-kamery-serii-select/xi1010cis-ir

А вот тут пример похожей реализации: https://habrahabr.ru/post/177071/

Для временного использования USB видеокамер думаю поставить USB-хаб с активным питанием на верхушке, тогда можно с верхушки дотянуться пятью метрами кабеля почти до всех точек.
Например такой: https://catalog.onliner.by/usbhub/dlink/dubh7

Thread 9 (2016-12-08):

Погодные датчики

Komzpa, 2016-12-08:
- скорость и направление ветра - на шапочке;
 - давление.

RudenkoPeter, 2016-12-08:
какие требования к выходным данным? через какой интерфейс их снимать в реальном времени?

Komzpa, 2016-12-08:
Требования от проекта OpenWeatherMap:

http://openweathermap.org/stations-30

комментарий разработчика:
"Нам интереснее всего - температура, давление, влажность и осадки ￼ Это то, что напрямую может участвовать в метеомодели и уточнять погодные данные по региону"

RudenkoPeter, 2016-12-08:
тогда нужна полноценная домашняя метеостанция:
http://www.advant-mpi.by/meteostancii.php
http://minsk.deal.by/p25301012-meteostantsiya-davis-vantage.html

Komzpa, 2016-12-08:
есть такое:

http://www.ebay.com/itm/La-Crosse-Technology-Wind-Speed-Weather-Station-327-1414W-/391463045904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

RudenkoPeter, 2016-12-08:
Он меряет только: скорость ветра, температуру, влажность. Нет ни давления, ни осадков. А ветер насколько я понял OpenWeatherMap не сильно интересен. Плюс в нем один - это полноценный внешний датчик с диапазоном -40+60

RudenkoPeter, 2017-01-30:
Пока нашел только профессиональные: http://www.meteomaster.ru/products/catalog/osnovnye-meteostantsii-DAVIS/
Ищу китайские аналоги

RudenkoPeter, 2017-01-30:
Вот бюджетные варианты:
http://www.ambientweather.com/amws2080.html

https://www.amazon.com/gp/product/B01HH4WZXG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

http://www.ebay.com/itm/Ambient-Weather-Wireless-Remote-Monitoring-Weather-Station-/252714338503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

RudenkoPeter, 2017-01-30:
Я бы рассмотрел вот на такой вариант хоть он и дороже:
http://www.ebay.com/itm/Davis-Instruments-Vantage-Vue-Wireless-Integrated-Rugged-Sensor-Sensor-Suite-New/381664572317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

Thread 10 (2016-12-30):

Аномально высокая влажность в туалете

Komzpa, 2016-12-30:
Зимовка показывает, что в туалете влажность больше, чем на улице. Нужно осушать.

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

RudenkoPeter, 2016-12-30:
На данный момент рассматриваю три причины: забор влажности из труб канализации или щелей пола, усугубляет отсутствие проветривания и вентиляции.
1. Налажу проветривание
2. Уберу источники влажности

RudenkoPeter, 2017-01-30:
В ближайшее время сделаю временные отверстия для проветривания, а после ремонта двери можно будет открыть окно.

Komzpa, 2017-01-30:
есть хоть какая-нибудь подтверждающая математика? :)

RudenkoPeter, 2017-01-30:
Подтверждающая что? Что если открыть окно влажность упадет?

Komzpa, 2017-01-30:
да. с пониманием, откуда она берётся, и при каких параметрах начнёт проявляться внутри дома.

RudenkoPeter, 2017-01-30:
Предварительно причины три:
1. Дождевая вода затекает под санузел
2. Испарения воду попадают в санузел через щели в полу
3. Влажность накапливается в помещении т.к. нет проветривания

Усугубляет ситуацию северное расположение санузла т.е. солнце нагревает только часть стены и дверь, а основной периметр находится постоянно в тени.

В доме такого не будет т.к.:

1. Пол герметичен и утеплен
2. Вода под дом затекает, но намного меньше чем под санузел
3. Высота помещения помогает циркуляции воздуха
4. Солнце нагревает помещение через большое окно

RudenkoPeter, 2017-03-17:
5 марта открыл верхнюю часть обшивки для проветривания + переставил датчик влажности в центр помещения. Раньше он лежал на полу.

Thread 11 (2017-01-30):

Дублирование интернета

Komzpa, 2017-01-30:
Нужна land line для интернета. Приезжать в деревню нажать "reconnect" неприкольно.

Самая ближайшая из доступных независимых - телефон на доме 24.

RudenkoPeter, 2017-01-30:
Варианты:
1. протянуть телефонную линию от участка 24 под землей
2. Протянуть сетевой кабель или Wi-fi от дома №24 (позволит объединить два участка в сеть)
3. Подать заявку на установку собственного телефонного номера на участке 57
4. Договорится с соседями о подключении к их интернету с оплатой

Komzpa, 2017-01-30:
Wifi уже не достал. Во что станет нормальная проводная сеть?

RudenkoPeter, 2017-01-30:
Расстояние около 600м
1. Провести по столбам витую пару стоит 350-450$
2. Провести новый телефон на 57й участок будет стоит меньше 300$ но придется подождать, позже подробности узнаю
3. Вести телефонный кабель от 24го дома не вижу смысла т.к. цена будет 300-350$ по воздуху, а под землей еще дороже

Komzpa, 2017-01-30:
ты учитываешь максимальную длину сегмента витой пары? 100..300м в зависимости от многих параметров оборудования и стандарта :)

RudenkoPeter, 2017-01-30:
Нет, этого не учел. Тогда вижу только один вариант - провести нормальный телефон на участок 57

RudenkoPeter, 2017-01-31:
Узнал подробности в Червенском сервис центре Белтелеком.
1. Новый телефонный номер провести на участок 57 нет возможности т.к. в деревне Ялча нет свободных линий (если только кто-то отключит свой телефон за ненадобностью)
2. Продублировать номер из дома 24 тоже не получиться.
3. Остается вариант переноса номера с участка 24 на участок 57, но для выяснения этой возможности надо пригласить специалистов Белтелеком. Специалисты могут приехать в начале лета и посмотреть есть ли возможность переноса с одного дома на другой. Телефонные кабеля в Ялче проложены под землей.

Komzpa, 2017-01-31:
нужен интернет. есть ли опции подключения интернета без телефонной линии? (точно умеют выдавать ethernet-модем с антенной и особой симкой)

RudenkoPeter, 2017-01-31:
Белтелеком кроме проводного интернета предлагает доступ к интернету через 2G и 3G. У него договор с МТС на облуживание их сети, поэтому это будет тоже самое, что купить симку МТС и поставить в 3G модем.

Komzpa, 2018-04-17:
интернет считаем задублированным.

Closed 2018-04-17.

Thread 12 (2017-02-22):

Розетки и освещение

RudenkoPeter, 2017-02-22:
После последних обсуждений:

**Розетки:**

4 розетки+1 управляемая возле лестницы
4 розетки+1 управляемая на кухне
4 розетки по центру внизу (планируется телевизор)
2 розетки+1 управляемая в спальне при входе
2 розетки в спальне возле кровати

**Освещение:**
5 потолочных регулируемых светильников наверху в спальне
такого типа только белые: http://potolokspec.ru/wp-content/uploads/potolochnye-svetilniki-vstraivaemye-tochechnye.jpg

Для освящения коридора, кухни и зала по два светильника на каждом столбе примерно такого типа:
http://inlamp.com.ua/data/big/240_agnes.jpg
https://ae01.alicdn.com/kf/HTB140jRIFXXXXc9XpXXq6xXFXXX1/LED-Modern-Wood-Wall-Lamp-Glass-Shade-Wall-Sconce-Bedroom-Corridor-Wall-Mounted-Lights-PW029.jpg
https://ae01.alicdn.com/kf/HTB1TG5FMVXXXXX1aFXXq6xXFXXXi.jpg

Также возможна люстра в центре для освещения нижнего помещения такого типа:
https://www.lihtarik.com.ua/img/full/379.jpg
http://first-lab.ru/upload/iblock/cb2/cb229d9a3c6d8d34040f65b09596007f.jpg

Светодиодную ленту перенести для подсветки лестницы и области кровати на втором этаже

Управляемое освещение:
Две люстры на столбах + люстра по центру+освещение на крыльце.

RudenkoPeter, 2017-03-17:
**3.3	установить розетки**
4 розетки+1 управляемая возле лестницы
4 розетки+1 управляемая на кухне
4 розетки по центру внизу (планируется телевизор)
2 розетки+1 управляемая в спальне при входе
2 розетки в спальне возле кровати
Нужна ли управляемая розетка насоса водопровода?

RudenkoPeter, 2017-03-17:
**3.2	установить светильники**
5 потолочных регулируемых светильников наверху в спальне
такого типа только белые: http://potolokspec.ru/wp-content/uploads/potolochnye-svetilniki-vstraivaemye-tochechnye.jpg

Для освящения коридора, кухни и зала по два светильника на каждом столбе примерно такого типа:
http://inlamp.com.ua/data/big/240_agnes.jpg
https://ae01.alicdn.com/kf/HTB140jRIFXXXXc9XpXXq6xXFXXX1/LED-Modern-Wood-Wall-Lamp-Glass-Shade-Wall-Sconce-Bedroom-Corridor-Wall-Mounted-Lights-PW029.jpg
https://ae01.alicdn.com/kf/HTB1TG5FMVXXXXX1aFXXq6xXFXXXi.jpg

Также возможна люстра в центре для освещения нижнего помещения такого типа:
https://www.lihtarik.com.ua/img/full/379.jpg
http://first-lab.ru/upload/iblock/cb2/cb229d9a3c6d8d34040f65b09596007f.jpg

Светодиодную ленту перенести для подсветки лестницы и области кровати на втором этаже

Управляемое освещение:
Две люстры на столбах + люстра по центру+освещение на крыльце.

RudenkoPeter, 2017-03-17:
**3.1	кабель для розеток/света/отопления**
Кабеля прокладываем часть в стенах, часть под полом первого этажа

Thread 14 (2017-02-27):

Отопление зимой

RudenkoPeter, 2017-02-27:
Планируется ли отапливать зимой в течении 2-3 дней?
Необходимо ли отапливать санузел?
Закладывать ли провода для будущих стационарных обогревателей или будут мобильные масленые?
Предлагаю электрические кварцевыми обогревателями:
 http://xn--e1agimdcqg.xn--90ais/
теплопит.бел

Komzpa, 2017-02-28:
сейчас нужна предсказуемая температура в серверной. провода закладывать.

RudenkoPeter, 2017-02-28:
ок. Утепляем серверный шкаф и закладываем провода для отопления санузла и дома стационарными электрическими обогревателями.

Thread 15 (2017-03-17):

Санузел

RudenkoPeter, 2017-03-17:
**Планируется следующее**:
1.1	переустановить раковину
1.2	утеплить стены и крышу санузла (перенос на 2018)
1.3	смонтировать пароизоляцию (перенос на 2018)
1.4	обшить стены вагонкой (перенос на 2018)
1.5	бойлер
1.6	душевой уголок

Пункты (1.1) (1.5) (1.6) делает один специалист поэтому разделять их нежелательно.
Пункты (1.2) (1.3) не зависят от других, но их разделять нельзя.
Пункт (1.4) независим, но не идет раньше пунктов (1.2) (1.3)

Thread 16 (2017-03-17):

Водопровод

RudenkoPeter, 2017-03-17:
**Планируется следующее:**
4.1	утеплить и звукоизолировать скважину
4.2	Закрепить трубы водопровода
4.3	утеплить трубы
4.4	установить быстросъем и слив для насоса

Если не планируется использовать воду зимой, то достаточно (4.4).
(4.2.) зависит от (1.1) и (4.4)
(4.3) возможно на данный момент не целесообразен

Komzpa, 2018-04-17:
не хватает впускного грубого фильтра, защиты насоса от холостого хода

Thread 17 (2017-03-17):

Второй этаж

RudenkoPeter, 2017-03-17:
**Планируется следующее:**
5.1	установить вытяжку на верху дома
5.2	смонтировать мембрану
5.3	уложить стружку и песок на второй этаж
5.4	уложить пол  второго этажа
5.5	закрепить обрешетку на потолке
5.6	обшить потолок доской
5.7	пошлифовать каркас (перенос на 2018)
5.8	нанести пропитку на каркас (перенос на 2018)
5.9	сделать постоянную лестницу (перенос на 2018)
5.10	покрыть лестницу пропиткой (перенос на 2018)
5.11	шлифовка лестницы (перенос на 2018)
5.12	сделать перила для лестницы (перенос на 2018)

Пункт (5.1) Заменяет слабую вытяжку на более мощную
Пункты (5.2-5.5) Взаимосвязаны их разделять нельзя
Пункт (5.6) возможно сделать позже, но тк пол и потолок делает один мастер, то лучше объединить с (5.4)
Пункты (5.7-5.12) Взаимосвязаны их разделять нельзя. Тк временная лестница исправна, то пункты не являются срочными

Komzpa, 2017-05-21:
вынес лестницу в #24

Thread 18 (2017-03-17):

Веранда

RudenkoPeter, 2017-03-17:
6.1	шлифовка пола и каркаса веранды (перенос на 2018)
6.2	пропитка пола и каркаса веранды (перенос на 2018)

Разделять пункты нельзя. Они не являются срочны тк дерево уже потемнело и дополнительный год на улице хуже не сделает. Возможно в будущем потребуется сделать веранду закрытой, тогда шлифовка будет более актуальна.

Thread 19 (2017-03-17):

Кровля на веранде

RudenkoPeter, 2017-03-17:

RudenkoPeter, 2017-03-17:
**Планируется следующее:**
8.1	закрепить верхний слой кровли (перенос на 2018)
8.2	смонтировать водоотливы сверху веранды (перенос на 2018)
8.3	смонтировать водоотливы снизу веранды (перенос на 2018)

Каждый пункт независим друг от друга.
Пункты (8.2) и (8.3) делает один специалист поэтому их разделять нежелательно.
По технологии пункт (8.2) лучше делать самым первым
Тк временная кровля дома простоит 3 года, то кровлю на веранде можно смело переносить на 2018 год

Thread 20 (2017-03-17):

Кровля дома

RudenkoPeter, 2017-03-17:
**Планируется следующее:**
9.1	закрепить верхний слой кровли
9.2	смонтировать водоотливы вверху дома
9.3	смонтировать водоотливы внизу дома
9.4	доделать верхушку
9.5	Сделать отмостку вокруг дома и веранды

После осмотра крыши весной пункты (9.1-9.4) можно перенести на 2018 год.
Пункт (9.5) является срочным тк вода с крыши попадает под дом и подмывает фундамент

Komzpa, 2017-05-21:
чем 9.5 отличается от #23 ?

RudenkoPeter, 2017-05-21:
#23  это касается внешнего вида пространства под домом, а 9.5 необходим для сохранения фундамента и уменьшения влажности под домом

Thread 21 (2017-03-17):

Купол дома

RudenkoPeter, 2017-03-17:
**Планируется следующее:**
10.1	смонтировать утеплитель в куполе
10.2	смонтировать обрешетку в куполе (перенос на 2018)
10.3	обшить фанерой
10.4	покрыть фанеру белой пропиткой
10.5	нанести пропитку на обрешетку (перенос на 2018)

Пункты (10.1) (10.3) и (10.4) взаимосвязаны их разделять нельзя
Пункты (10.2) и (10.5) носят декоративный характер поэтому их можно перенести на 2018год

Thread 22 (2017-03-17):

Внутренние стены дома

RudenkoPeter, 2017-03-17:
**Планируется следующее:**
11.1	смонтировать утеплитель в стены
11.2	обшить стены доской

Пункты не взаимосвязаны, но пункт (11.1) должен идти первым
Желательно сделать пункт (11.2) сразу, но из-за возможных изменений в проводке и больших затрат можно перенести на 2018 год

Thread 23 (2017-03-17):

Благоустройство

RudenkoPeter, 2017-03-17:
**Планируется следующее:**
12.1	закрыть сваи тканью

Пункт (12.1) носит декоративный характер. Лучше делать эти работы в последнюю очередь тк в пространство под домом будет необходим частый доступ. Так же есть вариант заменить ткань на деревянные бруски

Komzpa, 2018-04-17:
не хватает лючков:
 - для обслуживания воды
 - для доступа к садовому крану

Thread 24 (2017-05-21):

Лестница

Komzpa, 2017-05-21:
5.9	сделать постоянную лестницу (перенос на 2018)
5.10	покрыть лестницу пропиткой (перенос на 2018)
5.11	шлифовка лестницы (перенос на 2018)
5.12	сделать перила для лестницы (перенос на 2018)

Komzpa, 2017-05-21:
Пункты (5.9-5.12) Взаимосвязаны их разделять нельзя. Тк временная лестница исправна, то пункты не являются срочными

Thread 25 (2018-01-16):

Python/Django или Web2Python?

sg2017rm, 2018-01-16:
Здравствуйте, Петр!
Сразу хочу извиниться, что пишу вам в гитхаб в issue, а не в линкедин, но не получилось найти ваш линкедин :)
Я ищу веб-разработчика с опытом в Python под веб от 1 года до 99 лет, т.е. с опытом в Django или Flask, опытом работы с JavaScript-ом (желательно какой-нибудь высокоуровневый фреймворк, но пойдет и просто jQuery) и возможностью разговаривать по-английски (можно с ошибками и акцентом, это не страшно) :)
ИЛИ
Веб-разработчика на любой веб-технологии с опытом 2,5 - 5 лет с описанными выше английским, навыками JavaScript-а и желанием поработать на Python-е без просадки по доходам за счет смены технологии, а даже напротив :)
Напишите, пожалуйста, в скайп sg2017rm@gmail.com (это именно скайп), если это про вас.
Спасибо

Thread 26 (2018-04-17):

Треугольник под крышей вываливается

Komzpa, 2018-04-17:
- треугольник держится на четырёх шурупах. выпадает, убивая людей и мебель на первом этаже, если недозакрутить.
 - треугольник рядом выпадает и распадается на два, один - острым набором зубов из степлера.

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

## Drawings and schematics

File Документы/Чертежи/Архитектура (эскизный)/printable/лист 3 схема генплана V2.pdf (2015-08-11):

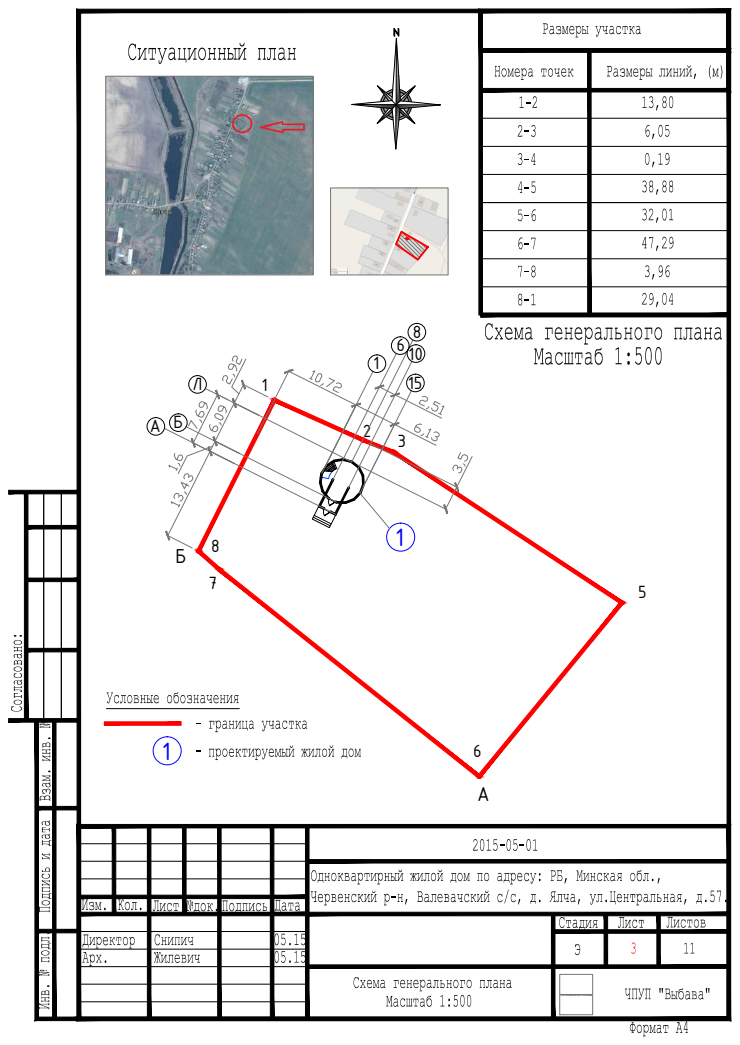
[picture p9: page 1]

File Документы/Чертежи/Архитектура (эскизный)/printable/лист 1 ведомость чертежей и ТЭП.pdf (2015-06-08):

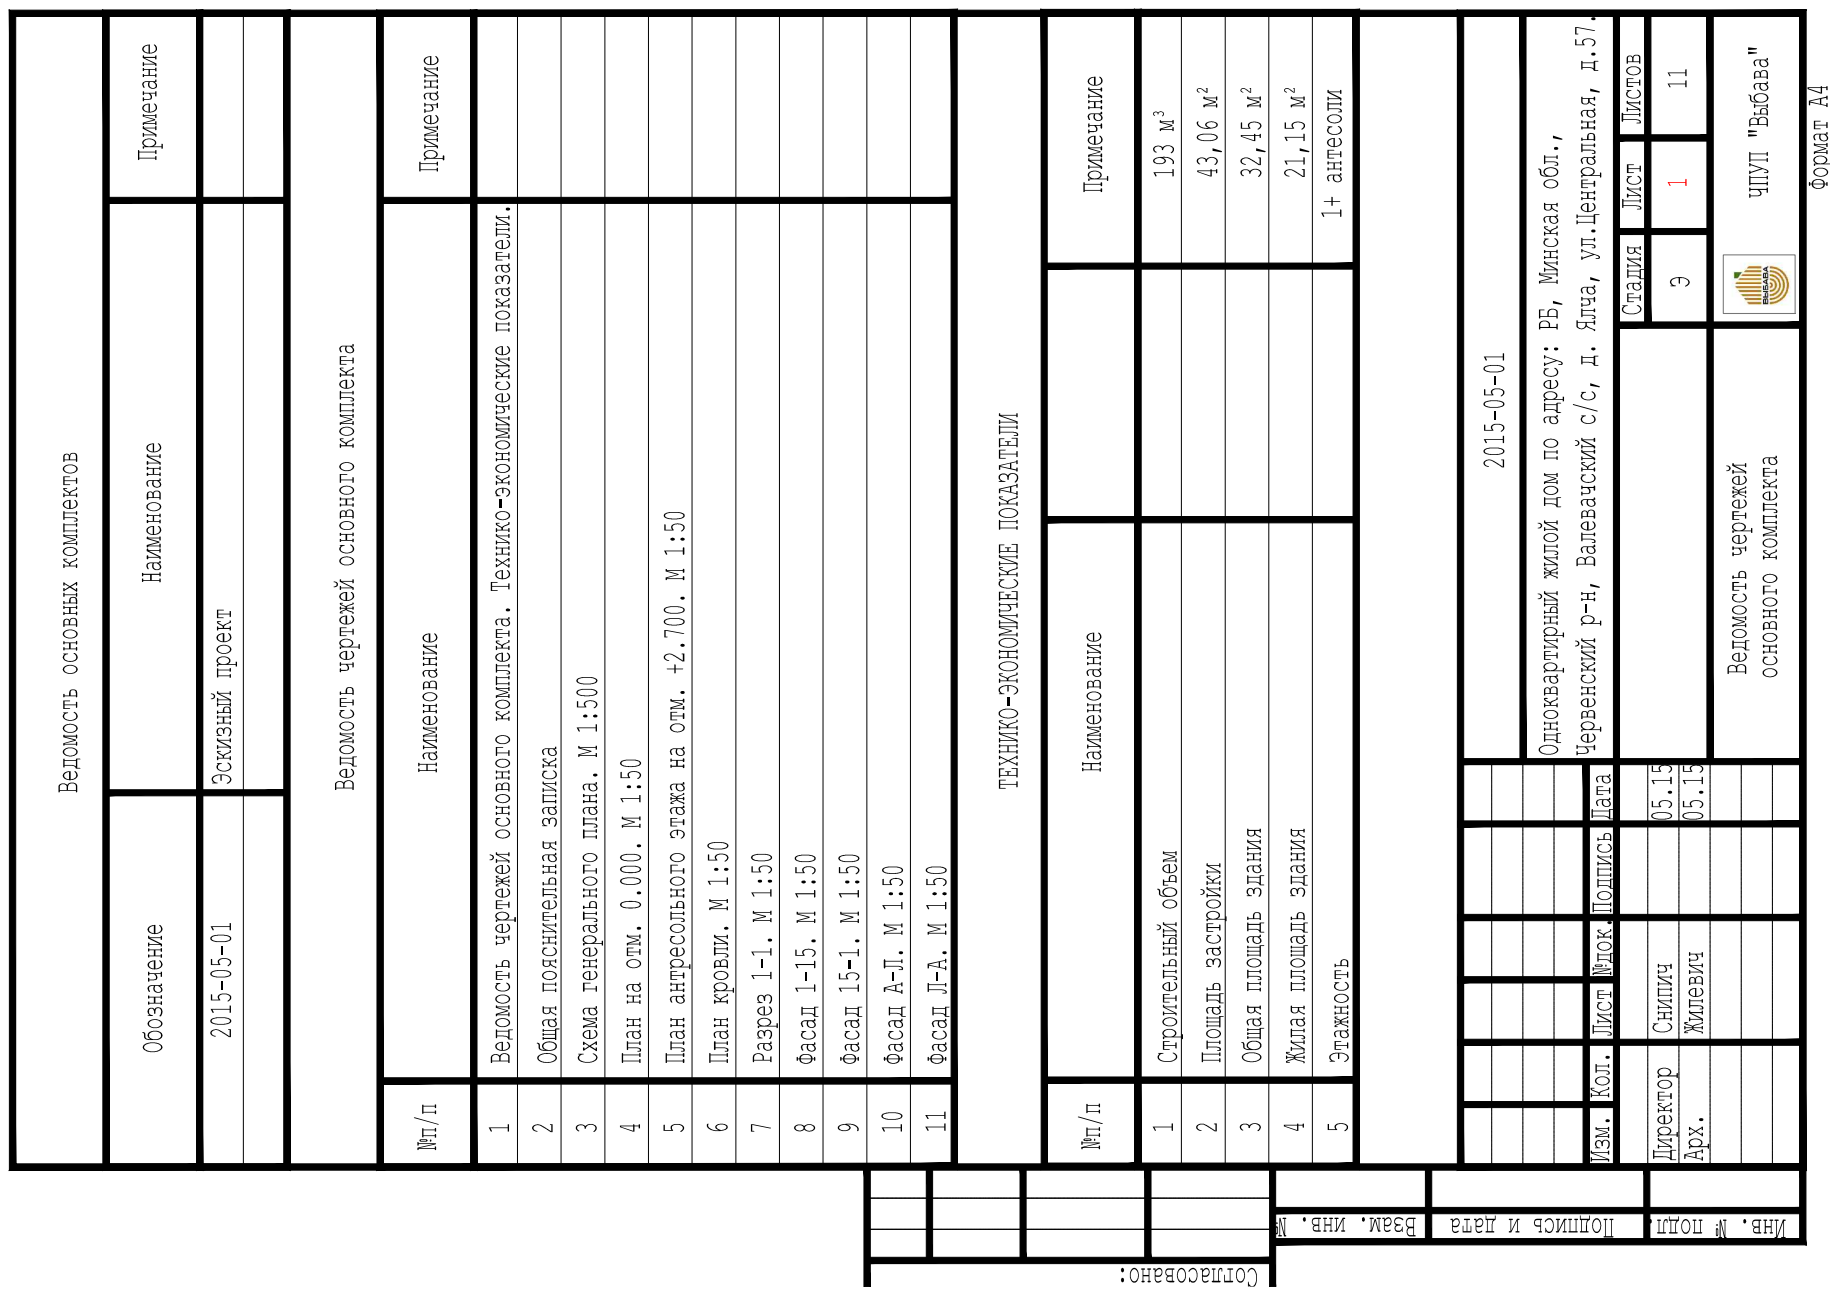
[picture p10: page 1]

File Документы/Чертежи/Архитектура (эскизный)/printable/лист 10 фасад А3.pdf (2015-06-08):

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

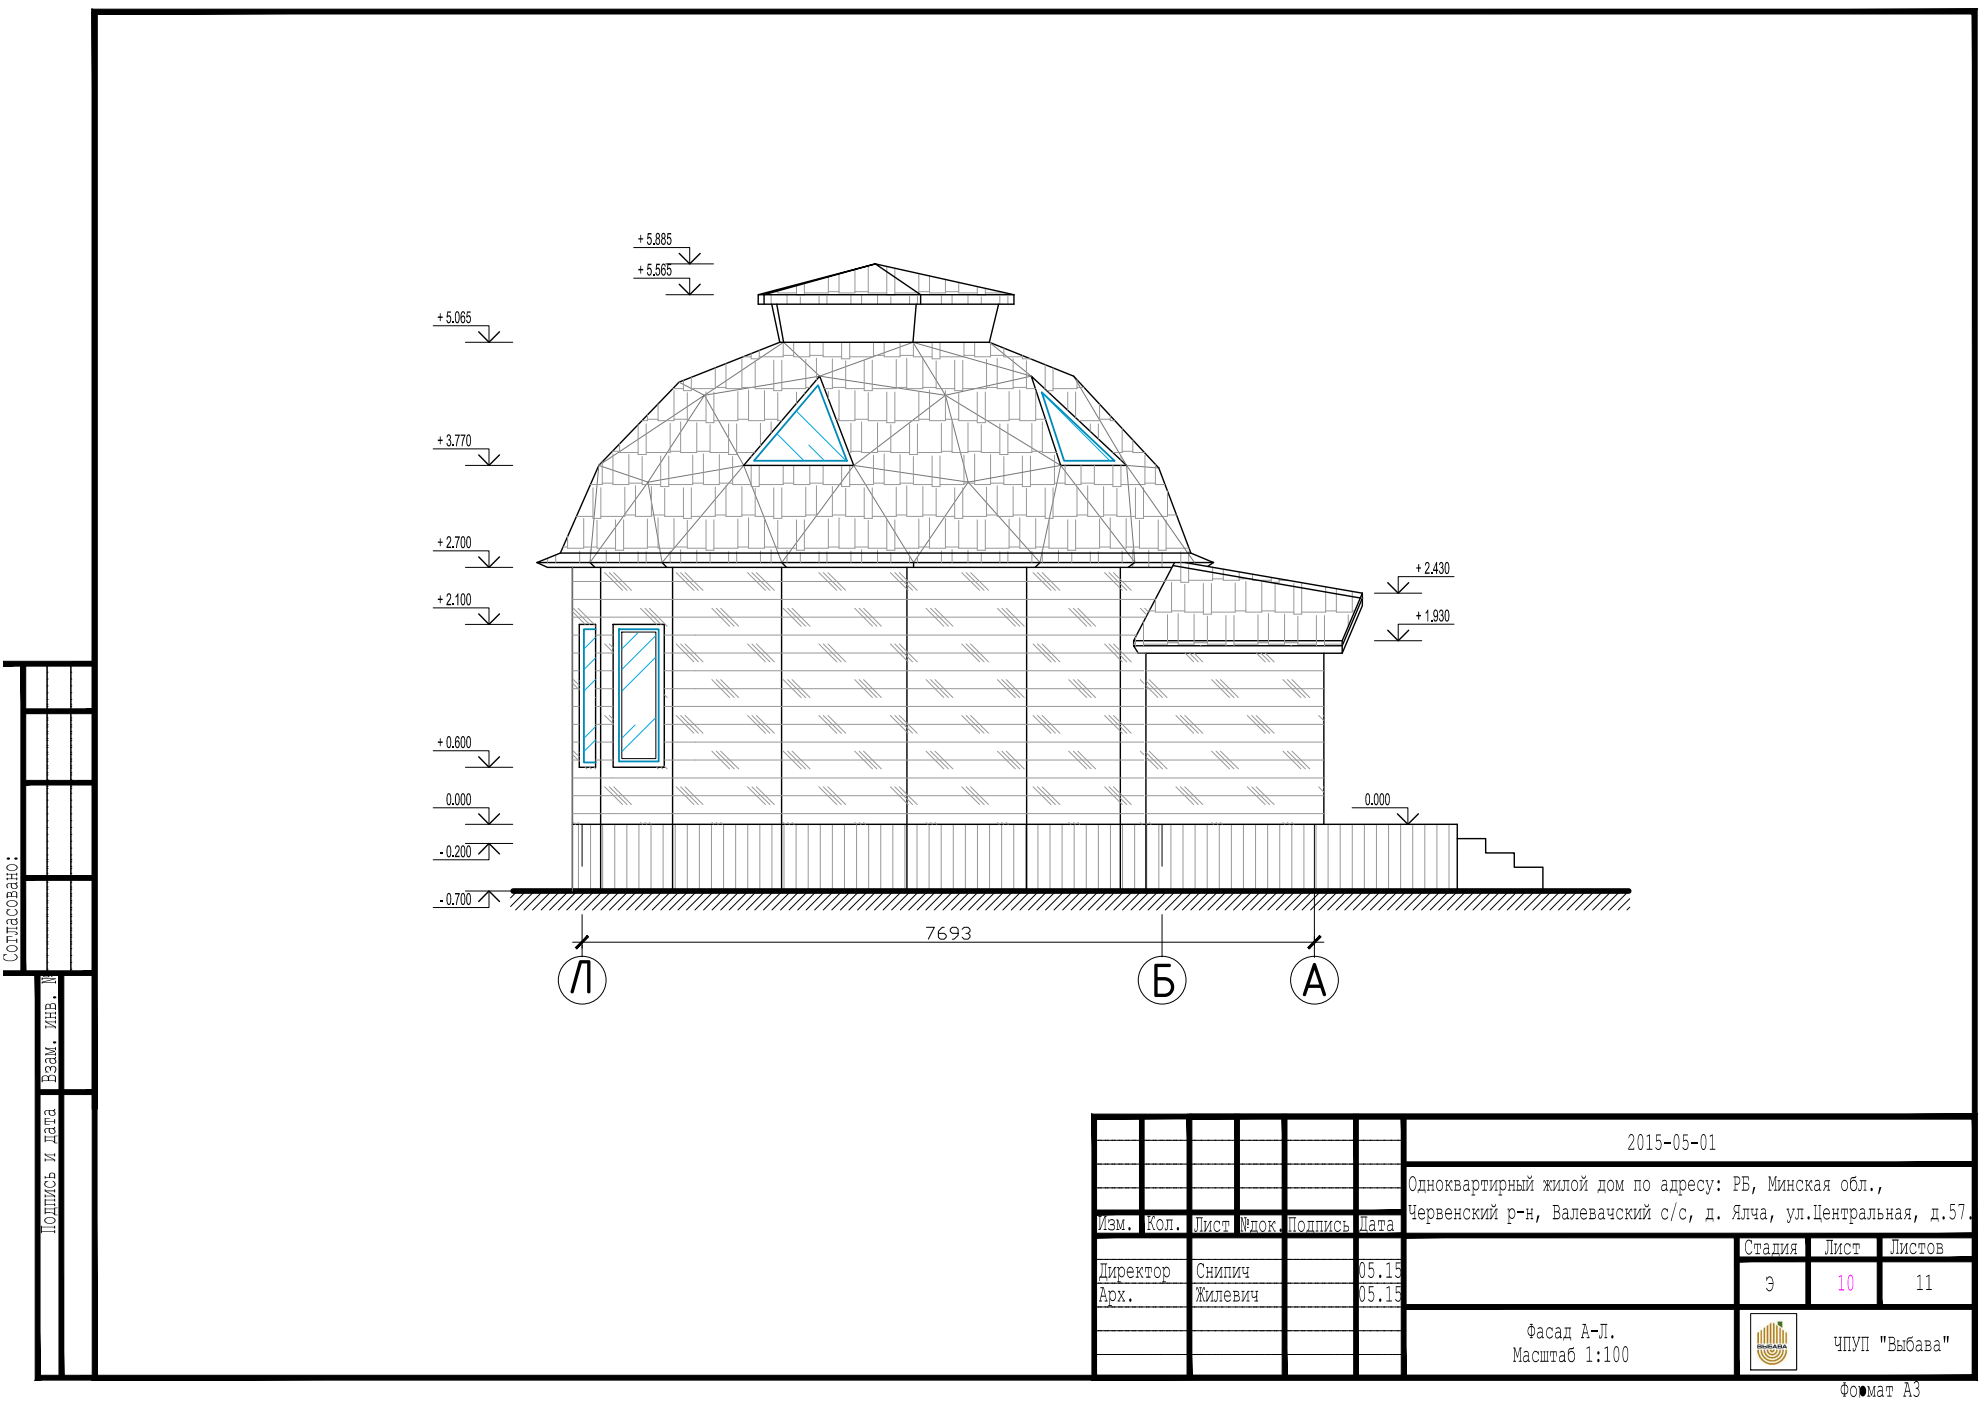
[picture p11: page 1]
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

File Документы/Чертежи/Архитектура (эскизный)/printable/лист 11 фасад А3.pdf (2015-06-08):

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

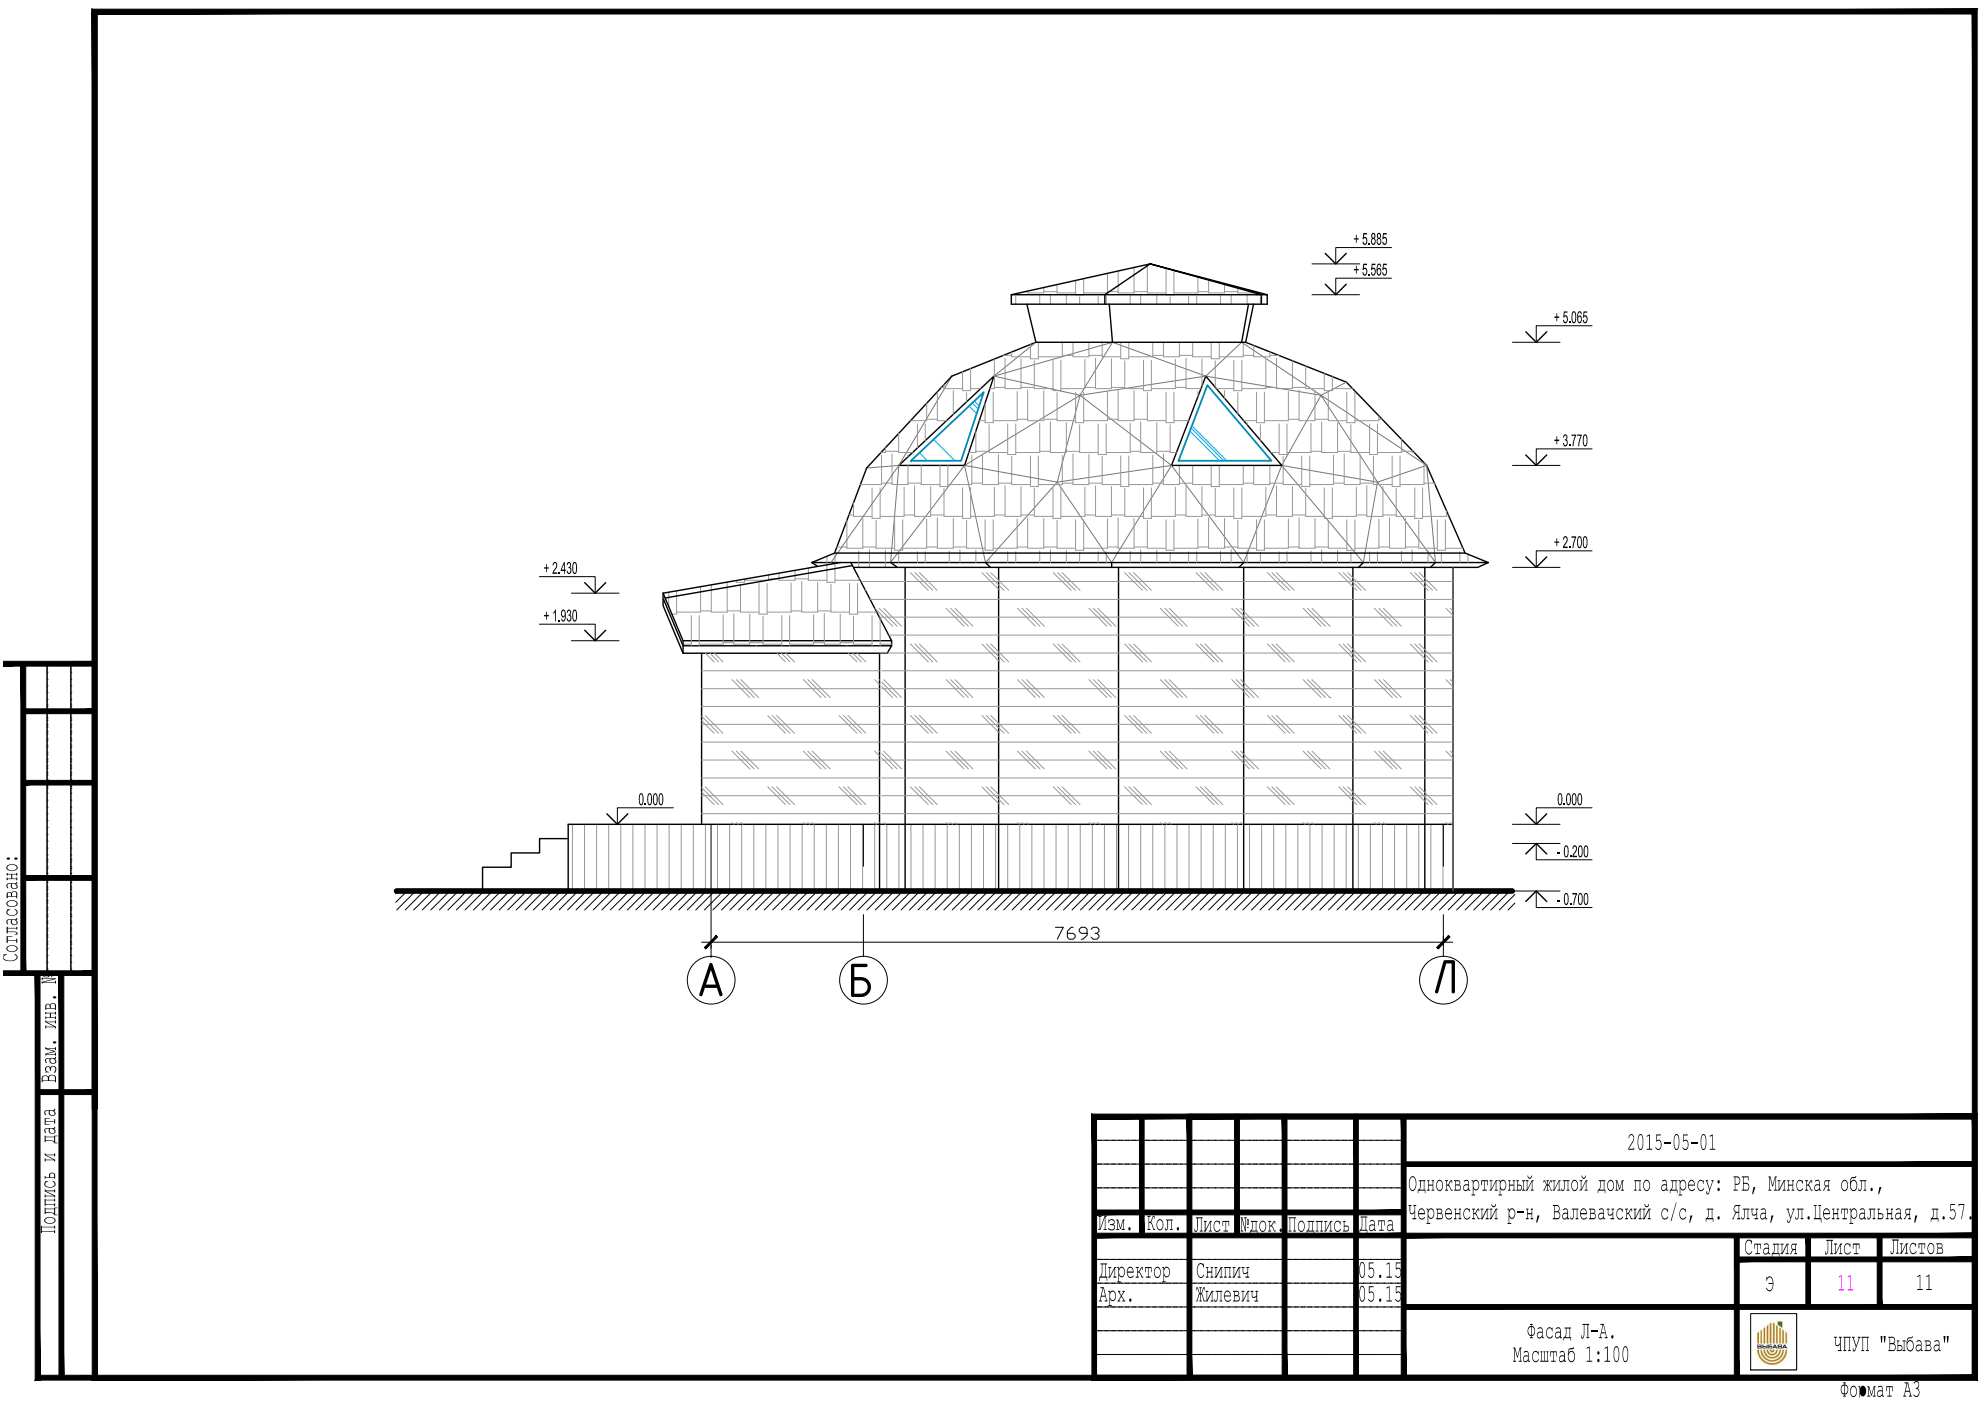
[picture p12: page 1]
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

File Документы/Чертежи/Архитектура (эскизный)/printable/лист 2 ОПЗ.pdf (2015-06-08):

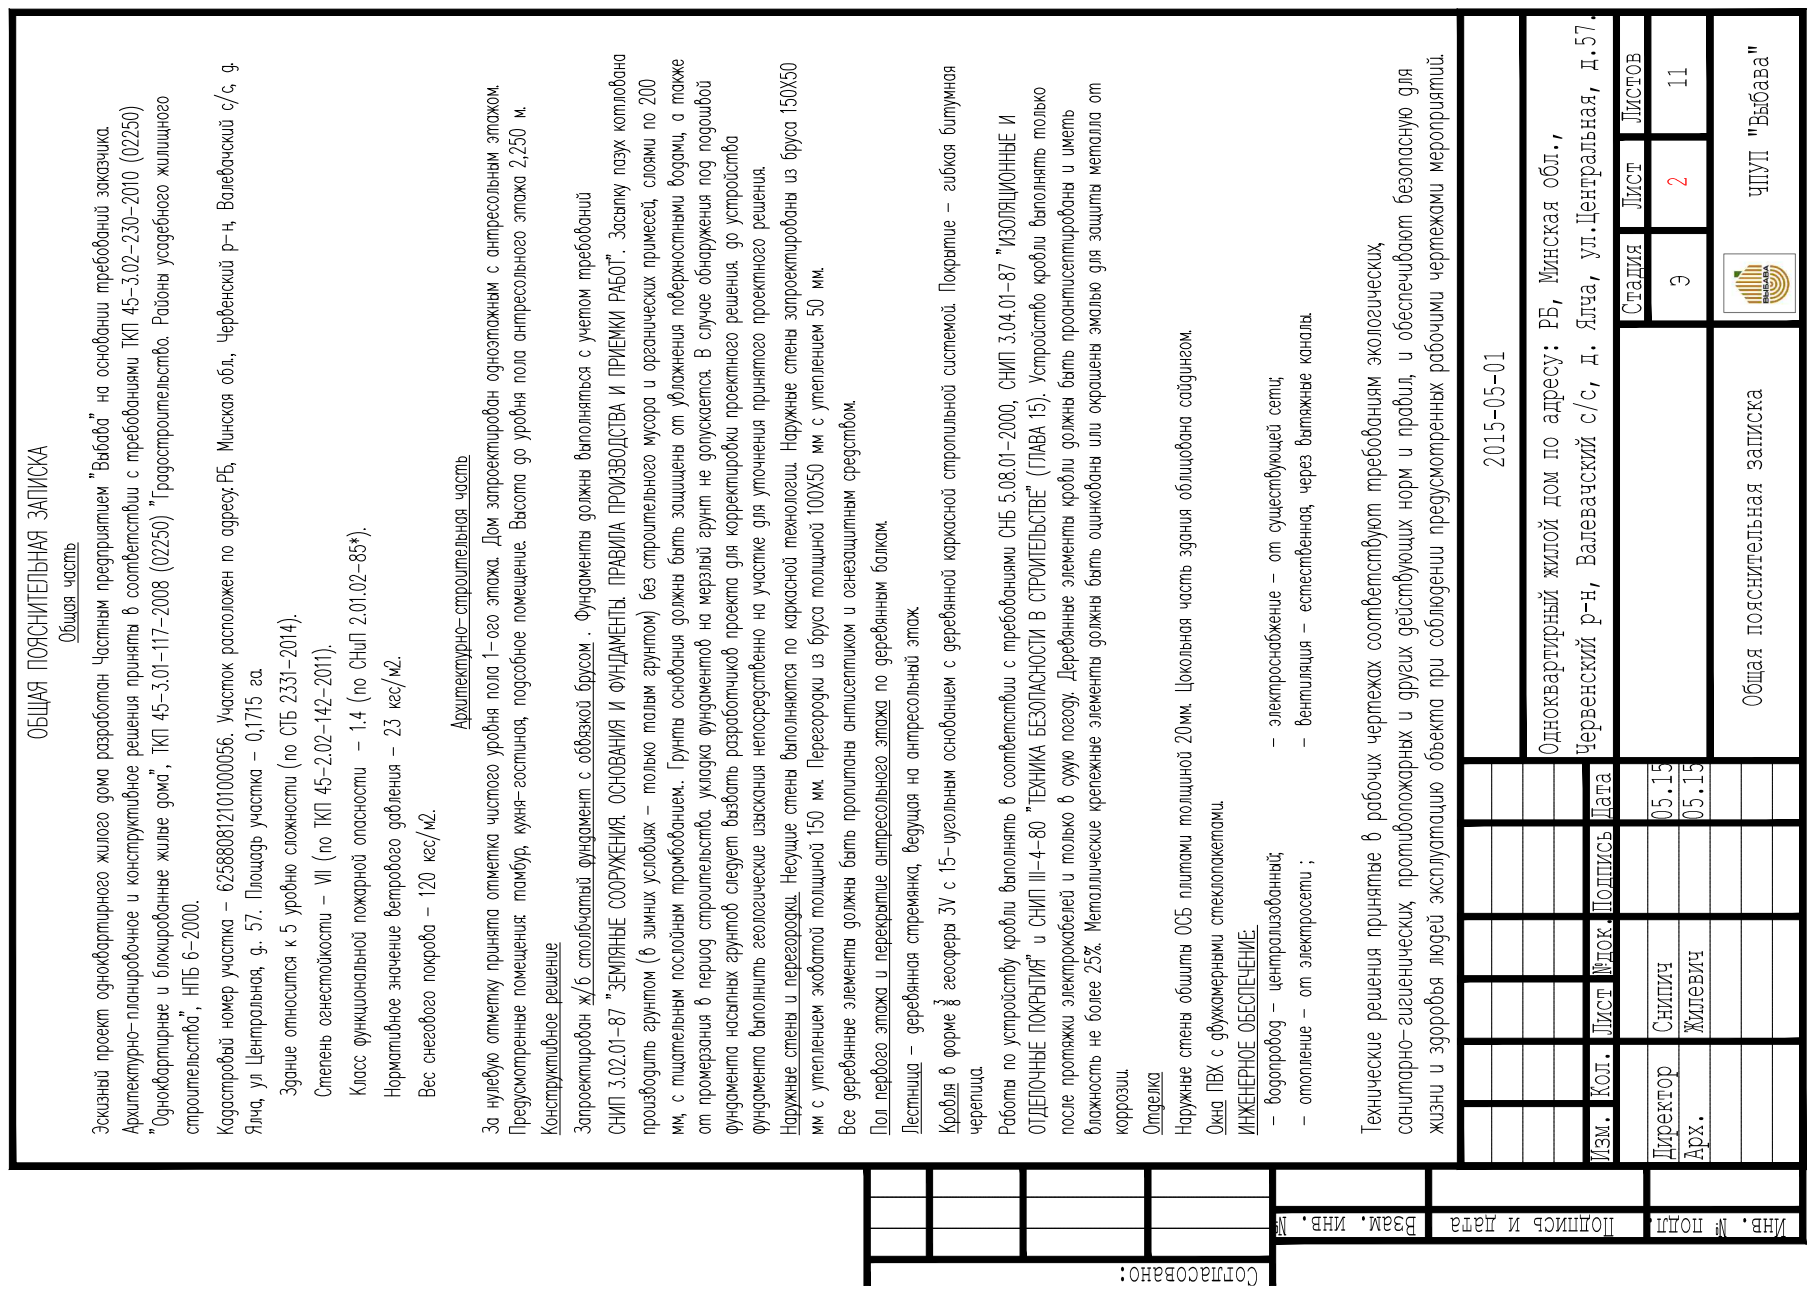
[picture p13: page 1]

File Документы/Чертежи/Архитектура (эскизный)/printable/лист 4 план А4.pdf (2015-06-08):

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

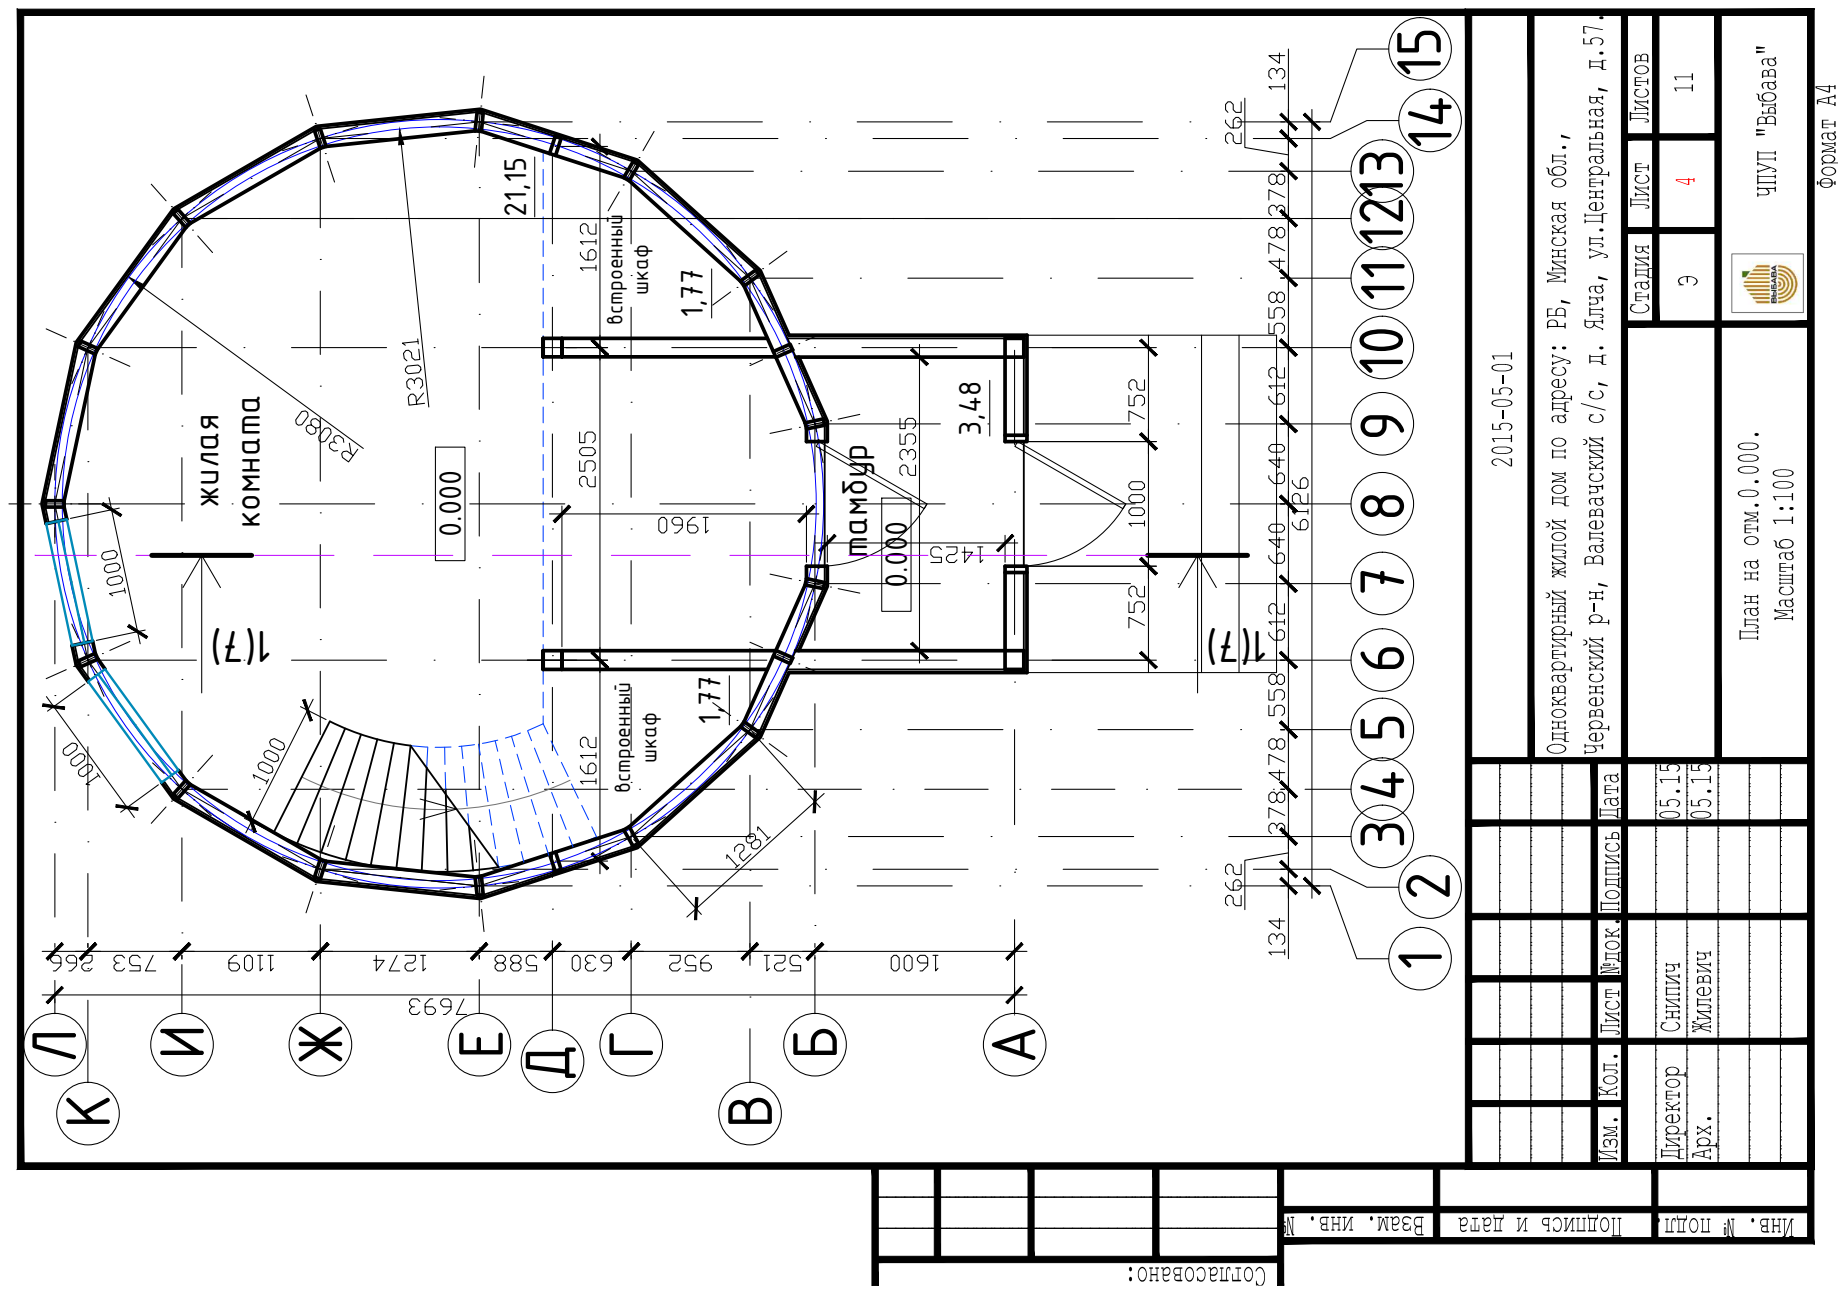
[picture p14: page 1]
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

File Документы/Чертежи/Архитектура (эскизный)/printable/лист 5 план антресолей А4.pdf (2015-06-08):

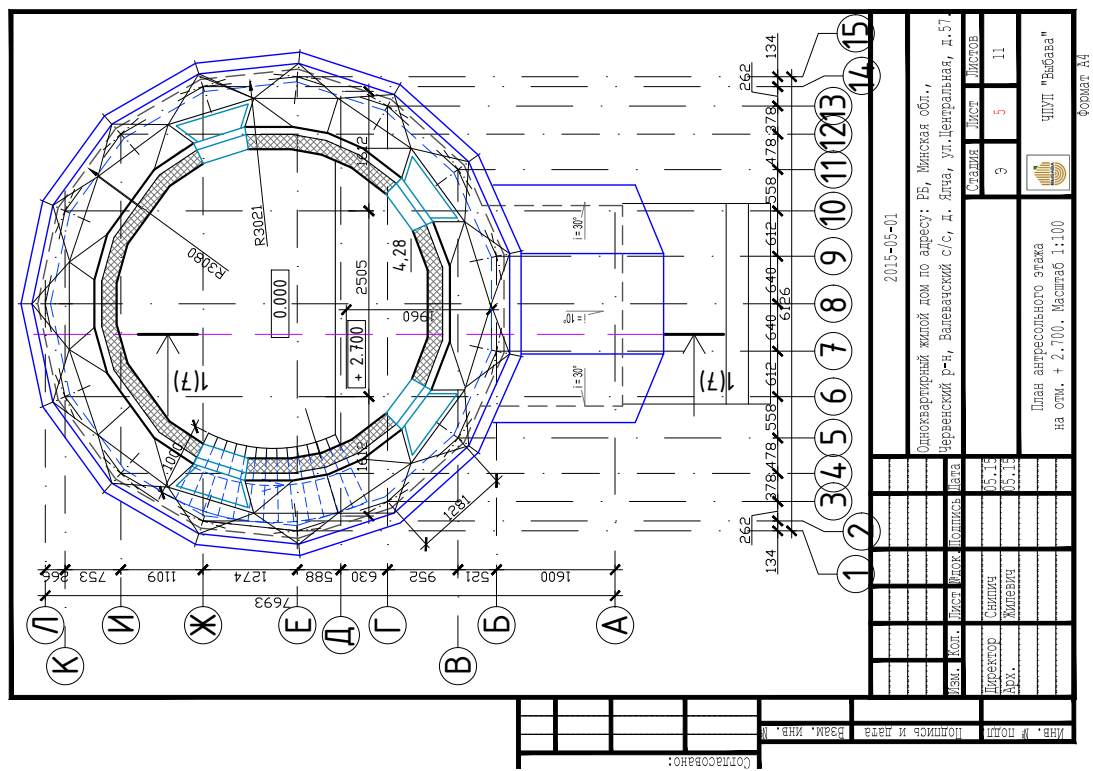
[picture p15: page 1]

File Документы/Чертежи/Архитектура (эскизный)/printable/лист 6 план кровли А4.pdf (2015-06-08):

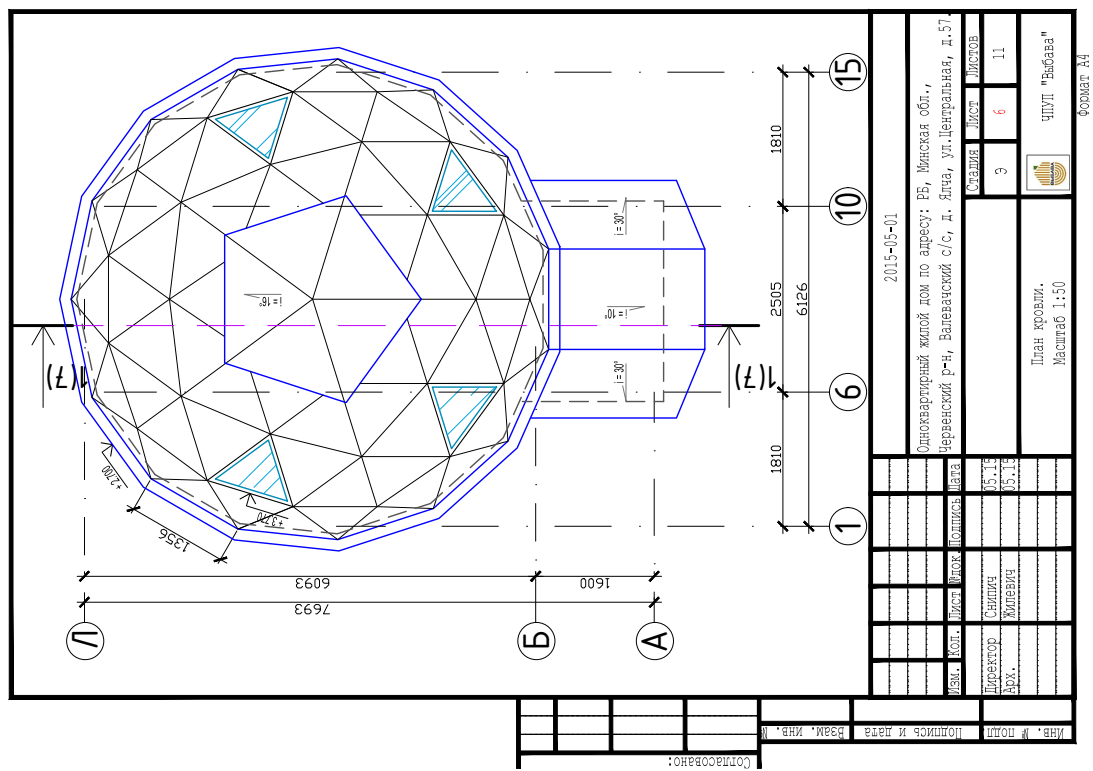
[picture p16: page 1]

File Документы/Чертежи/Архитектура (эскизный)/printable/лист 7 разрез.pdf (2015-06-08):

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

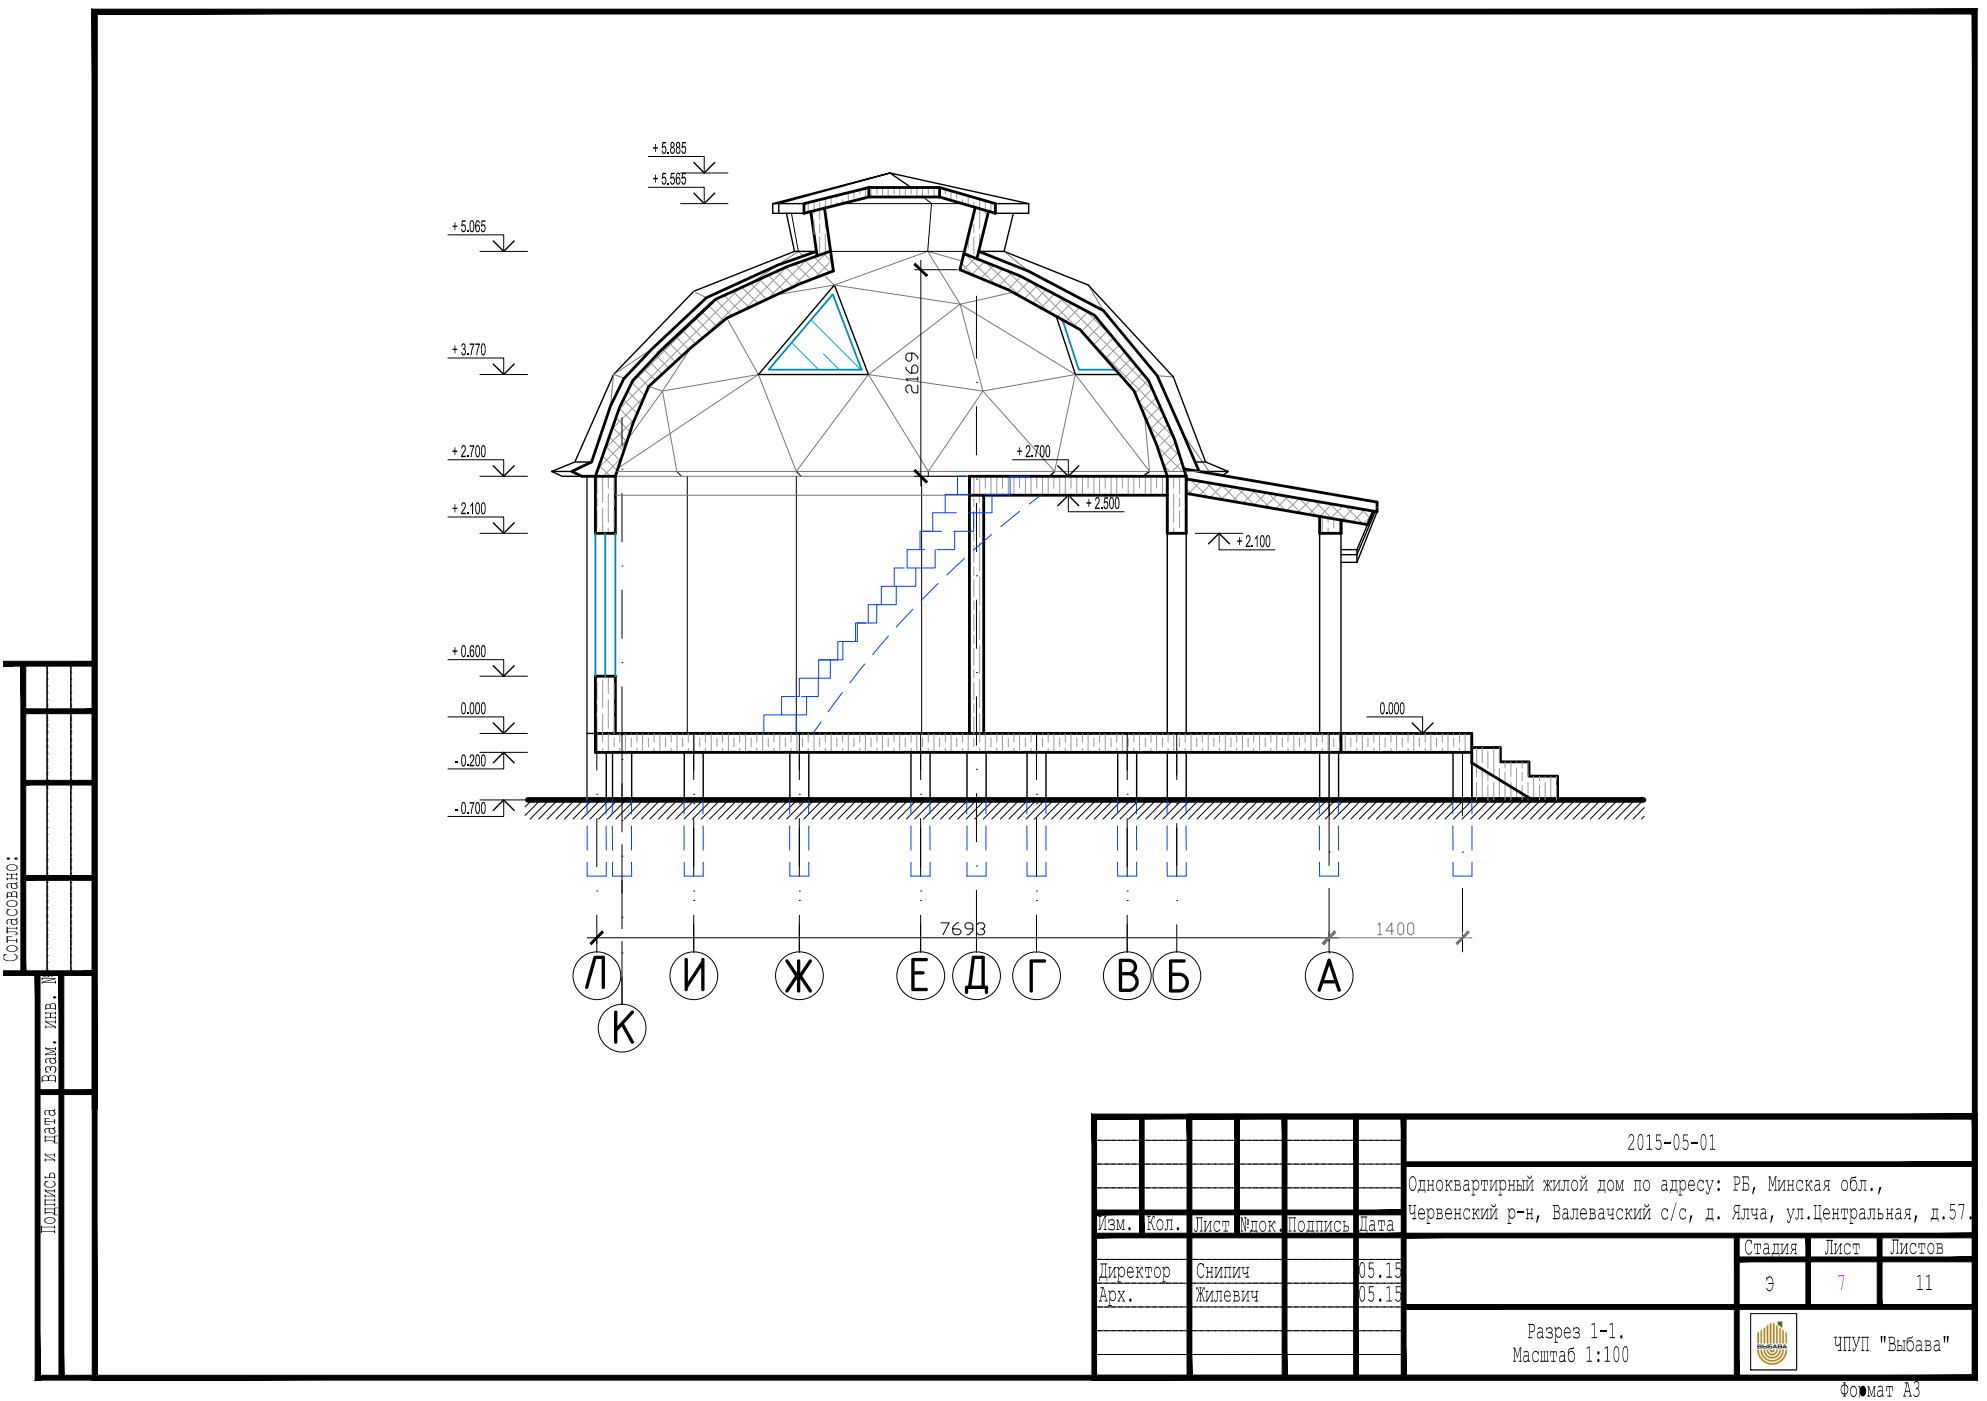
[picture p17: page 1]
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

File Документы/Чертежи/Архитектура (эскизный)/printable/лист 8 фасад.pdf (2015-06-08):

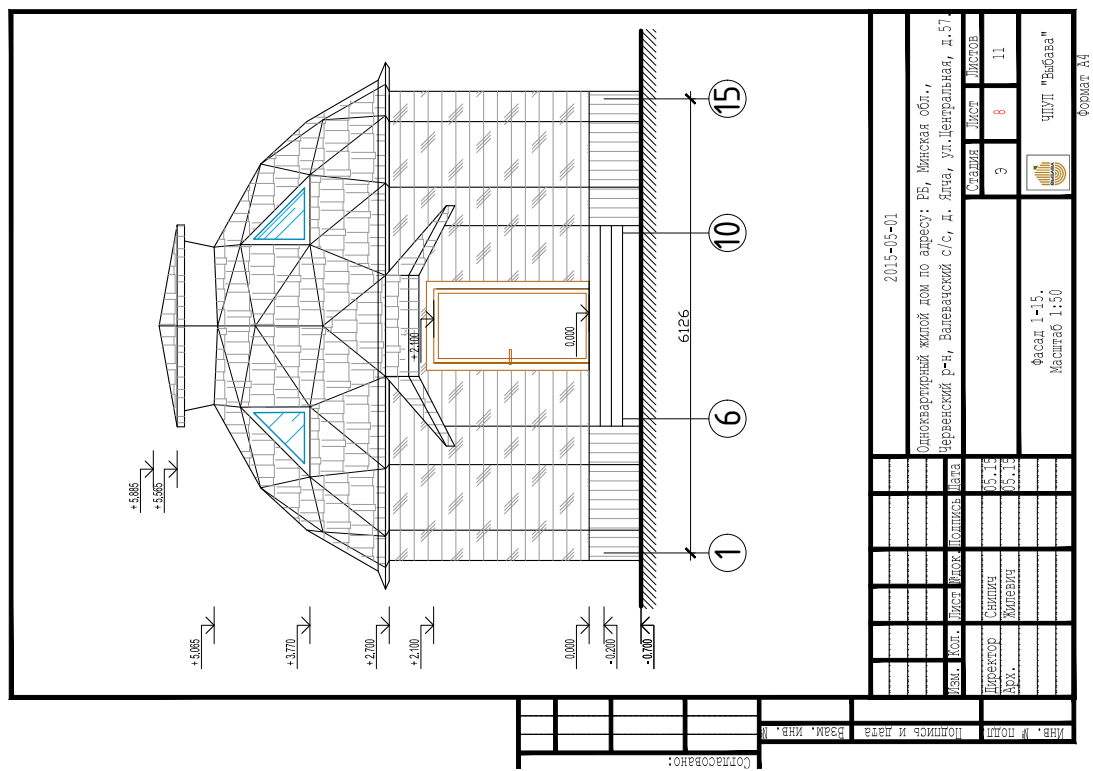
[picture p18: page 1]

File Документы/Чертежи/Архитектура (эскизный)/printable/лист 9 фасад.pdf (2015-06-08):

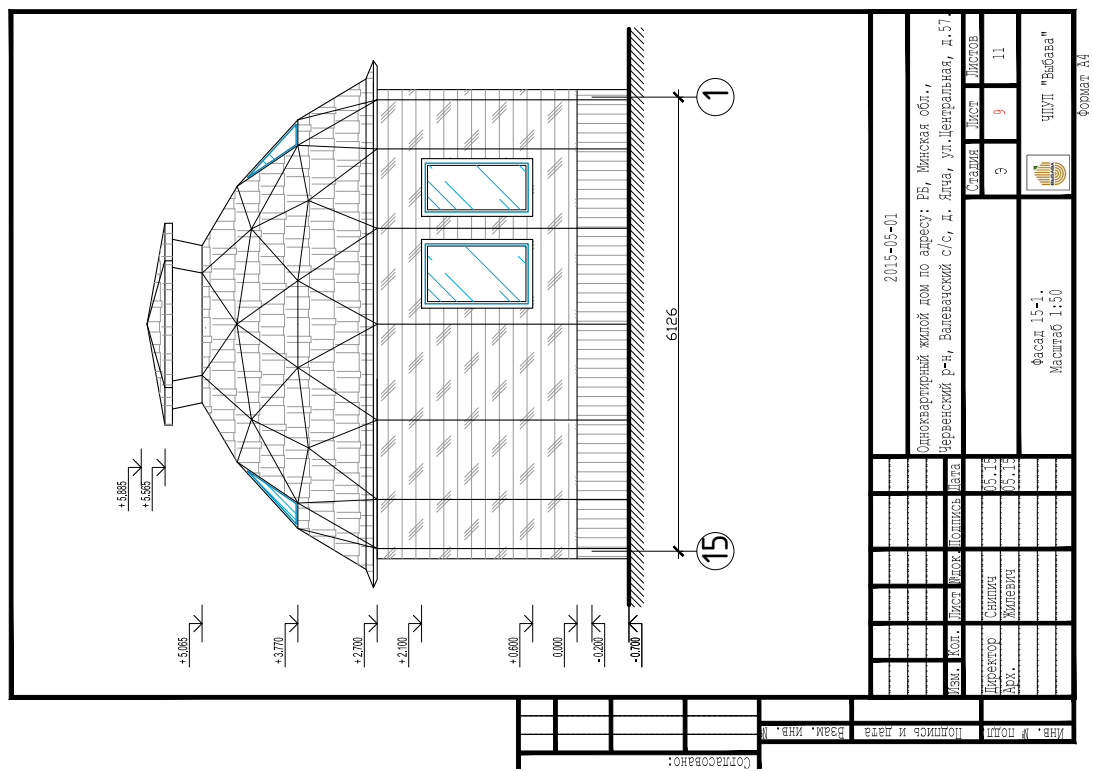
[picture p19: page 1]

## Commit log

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2015-06-07 старый файл
    завтра залью новый
    [смета_купол.xls]
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2015-06-08 поправил структуру каталогов
    - распаковал архивы
    - повернул-обрезал-пережал фотографии
    - отделил желаемое от действительного
    [Polusfera_v_liniakh_3V_6m.dwg, генплан.dwg, геодом.dwg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]
2015-06-08 залил 3д модель
    параметрическая модель для расчета купола
    [board_1.SLDPRT, board_2.SLDPRT, board_3.SLDPRT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]
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2015-06-15 переименовал папку
    разделил по папкам разные части документации
    [генплан.dwg, геодом.dwg]
2015-06-15 Переименовал в "чертежи"
    слово "проект" запутыет
    [генплан.dwg, геодом.dwg]
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2015-06-15 Запланировано
    Расходы на июнь месяц - план
    [июнь.csv]
2015-06-15 переименовал на цифры
    чтобы уйти от русских букв
    [06-2015.csv]
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2015-06-15 создал план расходов за май
    [2015-05.csv]
2015-06-15 исправил цену
    средняя стоимость архитектруы от 3 млн до 8 млн
    [2015-05.csv]
2015-06-15 добавил доставку
    не учел ранее доставку мотобура и бетономешалки
    [2015-06.csv]
2015-06-15 изменил ЗП на организационные
    [2015-05.csv, 2015-06.csv]
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2015-06-15 добавил в имена текущий курс
    [2015-05 - USD_15000.csv, 2015-06 - USD_15600.csv]
2015-06-15 Внес поправки по курск
    [2015-05.csv, 2015-06.csv]
2015-06-15 Откатил имя
    Курс зашил внутри
    [2015-05.csv, 2015-06.csv]
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2015-06-16 исправил курс
    в последней строке один нолик забыл
    [2015-05.csv]
2015-06-16 запланировал расходы
    до ноября месяца включительно
    [2015-07.csv, 2015-08.csv, 2015-09.csv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]
2015-06-16 исправил буквы
    [2015-07.csv, 2015-08.csv, 2015-10.csv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]
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2015-06-16 урезал расходы на пиломатериалы
    буду использовать меньше сечение
    [2015-07.csv]
2015-06-16 выросла цена за коннекторы
    [2015-08.csv]
2015-06-16 заменил кровлю на российскую
    цена снизилась
    [2015-09.csv]
2015-06-16 заменил двери и окна
    выбрал подешевле
    [2015-10.csv]
2015-06-16 убрал дорогую лестницу
    урезал организационные, пол сделают быстрее
    [2015-11.csv]
2015-06-16 убрал чистовой пол
    сначала надо отделку сделать, а потом пол
    [2015-11.csv]
2015-06-16 урезал расходы до 7500
    [2015-06.csv, 2015-08.csv, 2015-09.csv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]
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2015-07-04 исправил ошибку русского языка
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2015-08-11 сместили расположение дома на генплане
    причина - мешает расположение скважины
    [генплан v2.dwg]
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2015-08-11 обновил расходы на август
    важное сверху не важное снизу. буду тратить эти 1500 начиная с верхних
    строк
    [2015-08 текущее.csv]
2015-08-12 исправил синтаксис
    поставил запятые
    [2015-08 текущее.csv]
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2015-08-17 заказал пластины и уголки для бруса
    [пластины и уголок.dwg]
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2015-08-31 сделал планируемые расходы на сентябрь
    [2015-08 версия_2.csv, 2015-08.csv, 2015-09 текущее.csv]
2015-08-31 доверил гиту контроль версий
    [2015-08 версия_2.csv, 2015-08.csv, 2015-09 текущее.csv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]
2015-09-01 обновил планируемые расходы
    на основе новых чертежей и нового курса доллара
    [2015-09.csv]
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2015-09-01 аудит аудит, кого хочешь выбирай
    [rates.csv]
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2015-09-07 прикинул что можно сделать
    [терасса.dwg]
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2015-09-15 написал в штуках а не в метрах
    [2015-09.csv]
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2015-09-15 пересчитал треугольники с учетом зазора
    [Схема сборки и обшивки каркаса.dwg]
2015-09-15 сделал схему раскроя треугольников
    [треугольники.dwg]
2015-09-15 получил чертежи в электронном варианте
    [Спецификация балок обвязки.dwg]
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2015-09-26 чертежи на изготовление отливов
    [Металл-профиль.dwg]
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2015-10-03 изменил планируемое ближе к факту
    [2015-09.csv]
2015-10-03 составил план на октябрь
    итоговую сумму можно считать антикризисной
    [2015-10.csv]
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2015-10-05 обновил расходы до 9к
    [2015-10.csv]
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2015-10-19 исправил оформление
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2016-03-03 сводный отчет по стройке за 2015год
    [Расходы Ялча.xls]
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2016-03-03 исправил цитирование
    [_Расходы по стройке 2.csv]
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2016-03-08 таблица из опен офис
    [__Расходы по стройке 2.csv]
2016-03-08 удалил двойные строки в ячейке
    [__Расходы по стройке 2.csv]
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2016-03-10 экспорт из опен офис
    [_Rashod po stroyke 3.csv]
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2016-03-11 убрал лишние итого и добавил готовность
    [Rashod po stroyke.csv]
2016-03-11 готовность по задачам и общая
    [Rashod po stroyke.csv]
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2016-03-21 отчет по плану и факту выполнения
    [Расход по стройке.csv]
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2016-03-31 утвержденный бюджет до 1 июня
    [План расходов до 1 июня.csv]
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2016-03-31 вернул старую таблицу для 2015
    [Расходы 2015.xls, Расходы 2016.xls]
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2016-04-12 расходы на 12 апреля
    [Расходы 2016.csv]
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2016-04-16 текущие расходы на 15 апреля
    [Расходы 2016.csv]
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2016-05-04 расходы на 04 мая
    [Расходы 2016.csv]
2016-05-08 создал список оставшихся работ
    [Остаток работ 2016.csv]
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2016-05-08 создал отчет по перерасходу
    [Перерасход 2016.csv]
2016-05-08 расходы на 08 мая
    [Расходы 2016_.csv]
2016-05-25 расходы до 25 мая
    [Расходы 2016.csv]
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2016-06-07 расходы на 06 июня
    [Расходы 2016.csv]
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2016-06-23 План расходов на 2016
    [План расходов 2016.csv]
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2016-06-23 план расходов на этап2
    [План расходов 2016 этап2.csv]
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2016-07-22 порезал на куски по ~1к
    [План расходов этап2-1.csv, План расходов этап2-2.csv, План расходов этап2-3.csv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]
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2016-07-27 закупили материалы для пола
    [План расходов этап2 (1-4).csv]
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2016-08-26 расходы этап2 + итог
    [Расход 2016 этап2.csv]
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2016-08-26 заменил xls на csv
    [Расходы 2015.xls, Расходы 2016 этап2.csv, хронология расходов за 2015 год .csv]
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2016-08-28 Revert "плюс датчик для гаража"
    This reverts commit d765b86baf79257f92bf52eac9c9855a1a65e2fe.
    [План расходов 2016 этап3.csv]
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2016-09-04 переделал план этап3 с учетом доделать второй этаж
    [План расходов 2016 этап3.csv]
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2016-09-04 Revert "переделал план этап3 с учетом доделать второй этаж"
    This reverts commit 73f8442e65df904491c40029a15d9cffdc498e2b.
    [План расходов 2016 этап3.csv]
2016-09-04 Revert "расходы этап3"
    This reverts commit 9cd8c3cbcf7fcd49e04850c1dfe09ad1fc4d6687.
    [Расходы 2016 этап3.csv]
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2017-02-25 исправил названия и привязку к годам
    [План расходов 2016 этап4.csv, План расходов 2017 этап4.csv, План расходов 2017 этап5.csv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]
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2017-03-28 исправление проблем
    [План расходов 2017 общий.csv]
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2017-05-27 Revert "расходы за 21ю неделю 2017"
    This reverts commit db1827d9df47e84fa8a6c0aaf127aa5a578e0310.
2017-05-27 Revert "Revert "расходы за 21ю неделю 2017""
    This reverts commit 77251922e2bd5c45a5022977adc7726d0d9522e2.
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
